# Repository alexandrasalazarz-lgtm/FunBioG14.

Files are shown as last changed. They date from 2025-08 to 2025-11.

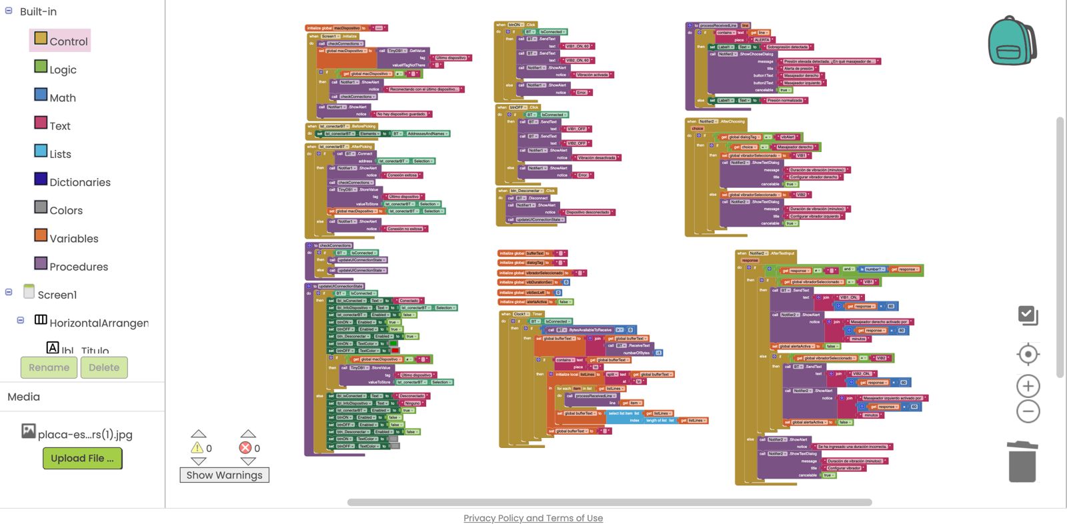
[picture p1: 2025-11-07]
ENTREGABLES/Entregable 10/Imagen aplicación .jpg

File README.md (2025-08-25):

![LOGOPUCP]((https://github.com/alexandrasalazarz-lgtm/FunBioG14./blob/cd670214b224eb7a91b062338901eb562789b06d/IMAGENES/361625433-f5917d88-32cc-4da6-9d7f-f75349cf09a3.png))

# Bienvenidos al repositorio del Grupo 14 de "Fundamentos de Biodiseño"

## Integrantes:

* **Tatiana Abigail Quispe Cueva** *tatiana.quispe@upch.edu.pe*

* **Ivanna Jael Rodriguez Cruz** *ivanna.rodriguez@upch.pe*

* **Jared Matias Neciosup Villarreal** *jared.neciosup@upch.pe*

* **Sebastian Adriano Reymundo Capcha** *sebastian.reymundo@upch.pe*

* **Luciana Mercedes Saenz Villarreal** *luciana.saenz@upch.pe*

* **Alexandra Estephania Salazar Zarate** *alexandra.salazar.z@upch.pe*

## INFORMACION DEL PROYECTO
**Temática:**

Diseñar y prototipar soluciones biomedicas para mejorar la calidad de vida de pacientes con artrosis

**Problemática:**

La artrosis es una enfermedad degenerativa la cual afecta principalmente al cartílago articular. Esta afección causa distintas limitaciones en el paciente, como dolor, rigidez y reducción del rango de movimiento en las articulaciones afectadas [1,2]. Además, según la OMS, la mayor prevalencia de esta enfermedad se encuentra en las mujeres, debido a distintos factores como factores hormonales, genéticos, mayor esperanza de vida, etc. El identificar los factores de riesgo que afectan a las mujeres podria ayudar a diseñar mejores estrategias de prevención y tratamiento en el futuro. [3]

**Justificación:**

La artrosis es una afección osteomuscular que contribuye en mayor porcentaje al total de años vividos con discapacidad. Puesto que es más prevalente en las personas de edad (alrededor del 70% son mayores de 55 años), se prevé que la prevalencia mundial de la artrosis aumente con el envejecimiento de la población. En la actualidad, a nivel mundial, 344 millones de personas que padecen esta enfermedad experimentan dolores moderados y fuertes. Esto reduce significativamente la calidad de vida que poseen, puesto que la enfermedad no solo tiene un impacto físico, sino también mental. 

**Referencias:**

[1] “Osteoarthritis,” World Health Organization, Fact Sheet, Jul. 14, 2023. [Online]. Available: https://www.who.int/news-room/fact-sheets/detail/osteoarthritis. [Accessed: Aug. 22, 2025].

[2] X. Mas Garriga, “Definición, etiopatogenia, clasificación y formas de presentación [Definition, etiology, classification and presentation forms],” Aten Primaria, vol. 46, no. Suppl 1, pp. 3–10, Jan. 2014, doi: 10.1016/S0212-6567(14)70037-X.

[3] I. A. Szilagyi *et al.*, “A systematic review of the sex differences in risk factors for knee osteoarthritis,” *Rheumatology*, vol., no., Dec. 2022, DOI: 10.1093/rheumatology/keac688.

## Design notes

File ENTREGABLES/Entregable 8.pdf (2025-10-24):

# ENTREGABLE Nº8

## Metodología VDI

Autores:

Rodríguez Cruz, Ivanna Jael

Saenz Villarreal, Luciana Mercedes

Reymundo Capcha, Sebastián Adriano

Neciosup Villarreal, Jared Matias

Salazar Zárate, Alexandra Estephania

Quispe Cueva, Tatiana Abigail

Profesor:

Juan Manuel Zuñiga

Curso:

Fundamentos de Biodiseño

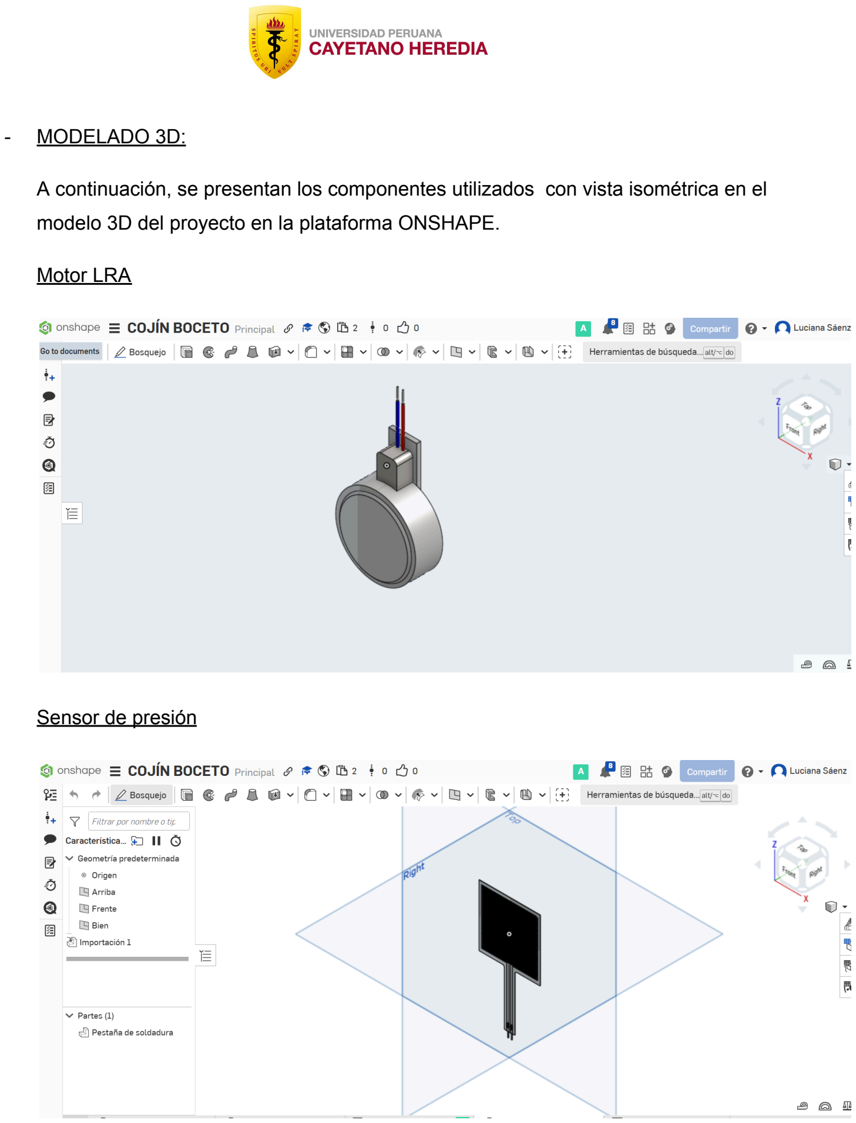
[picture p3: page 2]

- MODELADO 3D:

A continuación, se presentan los componentes utilizados con vista isométrica en el modelo 3D del proyecto en la plataforma ONSHAPE.

Motor LRA

Sensor de presión

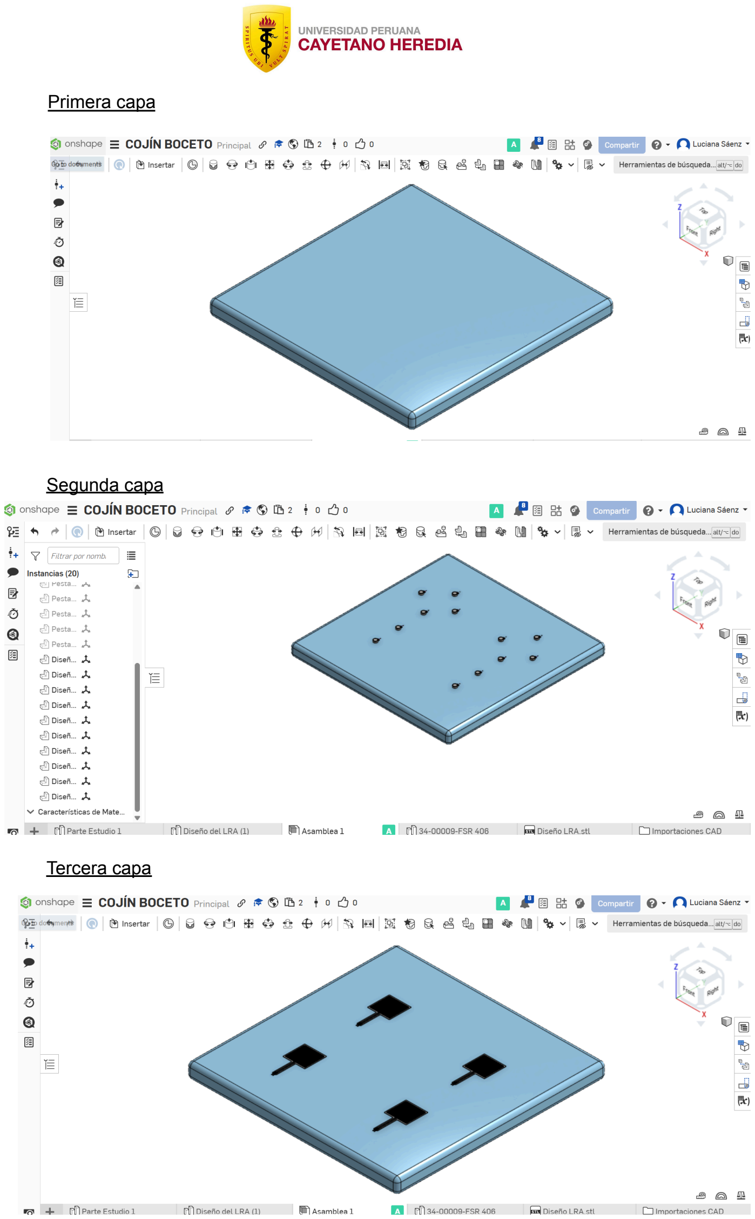
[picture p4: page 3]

Primera capa

Segunda capa

Tercera capa

Link del prototipo 3D:
https://cad.onshape.com/documents/2938b71a9a714207a594875f/w/f9e5938a32016dca3148457c/e/6e5b0f27c55fd5b3ef6440cf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 (https://cad.onshape.com/documents/2938b71a9a714207a594875f/w/f9e5938a32016dca3148457c/e/6e5b0f27c55fd5b3ef6440cf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)

Caja de componentes:

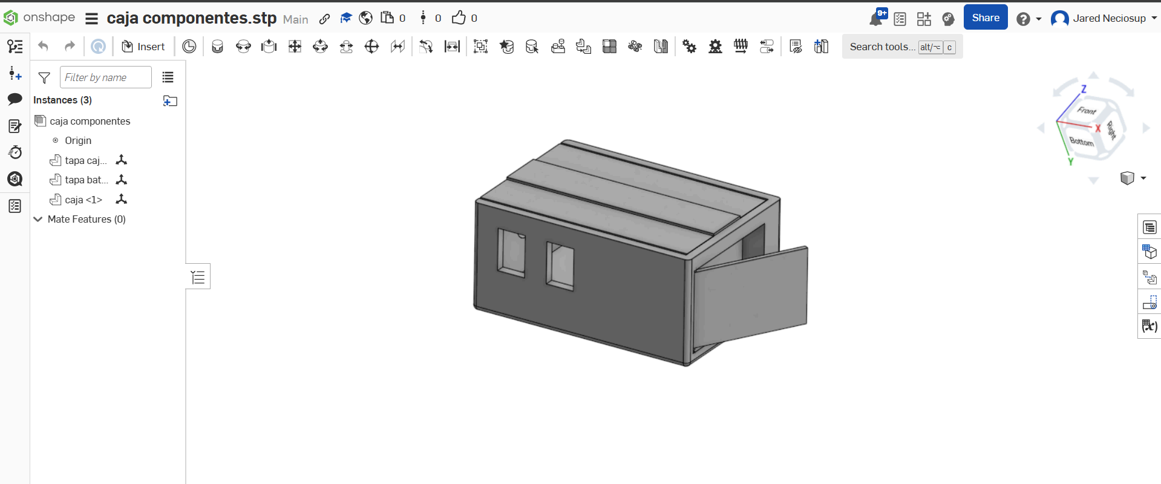
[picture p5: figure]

- Estructura:

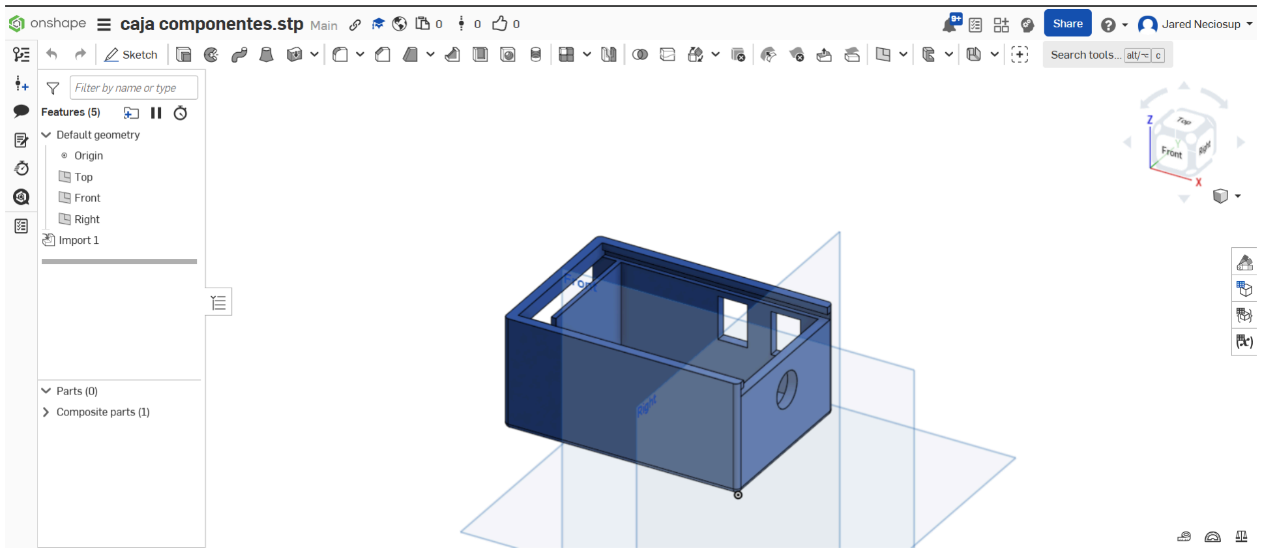
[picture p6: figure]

- Tapa:

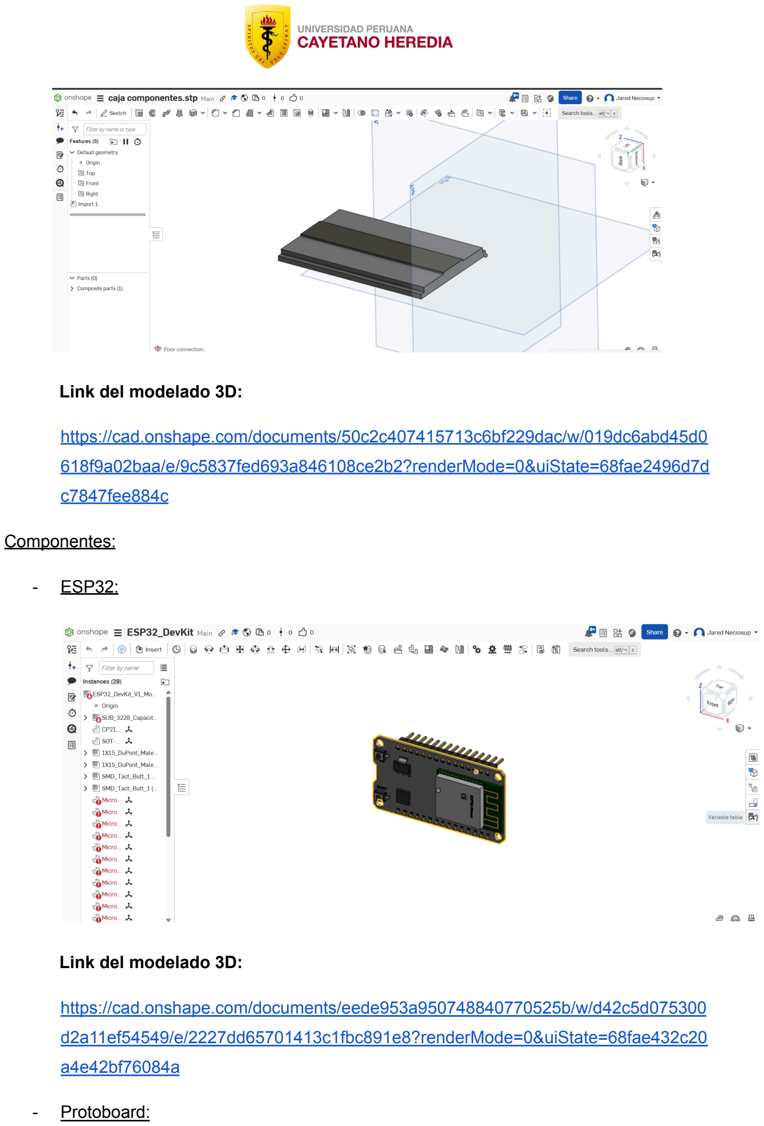
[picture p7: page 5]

Link del modelado 3D:

https://cad.onshape.com/documents/50c2c407415713c6bf229dac/w/019dc6abd45d0618f9a02baa/e/9c5837fed693a846108ce2b2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 c7847fee884c (https://cad.onshape.com/documents/50c2c407415713c6bf229dac/w/019dc6abd45d0618f9a02baa/e/9c5837fed693a846108ce2b2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)

Componentes:

- ESP32:

Link del modelado 3D:

https://cad.onshape.com/documents/eede953a950748840770525b/w/d42c5d075300d2a11ef54549/e/2227dd65701413c1fbc891e8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 a4e42bf76084a (https://cad.onshape.com/documents/eede953a950748840770525b/w/d42c5d075300d2a11ef54549/e/2227dd65701413c1fbc891e8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)

- Protoboard:

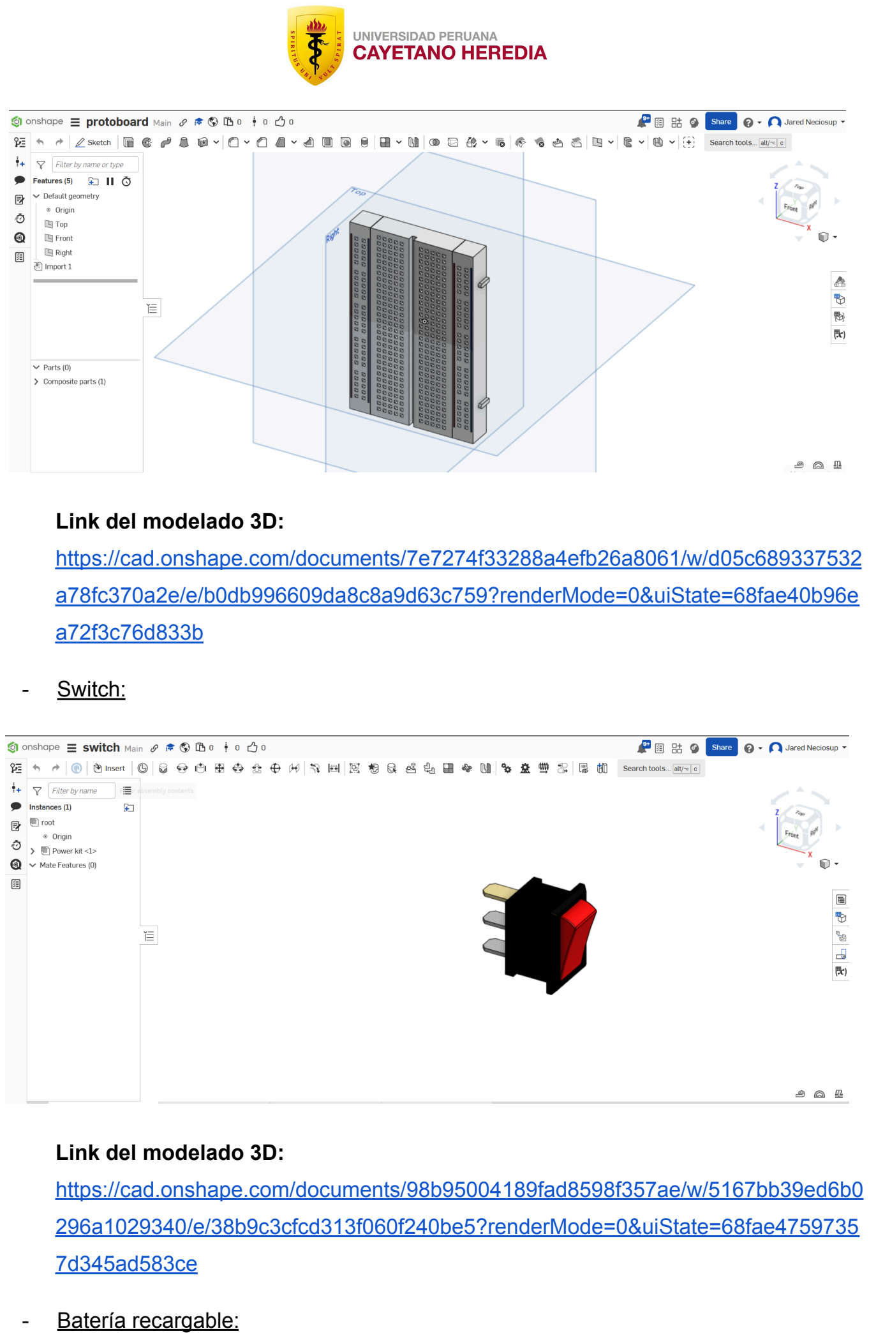
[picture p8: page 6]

Link del modelado 3D:
https://cad.onshape.com/documents/7e7274f33288a4efb26a8061/w/d05c689337532a78fc370a2e/e/b0db996609da8c8a9d63c759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 a72f3c76d833b (https://cad.onshape.com/documents/7e7274f33288a4efb26a8061/w/d05c689337532a78fc370a2e/e/b0db996609da8c8a9d63c759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)
- Switch:

Link del modelado 3D:
https://cad.onshape.com/documents/98b95004189fad8598f357ae/w/5167bb39ed6b0296a1029340/e/38b9c3cfcd313f060f240be5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 7d345ad583ce (https://cad.onshape.com/documents/98b95004189fad8598f357ae/w/5167bb39ed6b0296a1029340/e/38b9c3cfcd313f060f240be5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)
- Batería recargable:

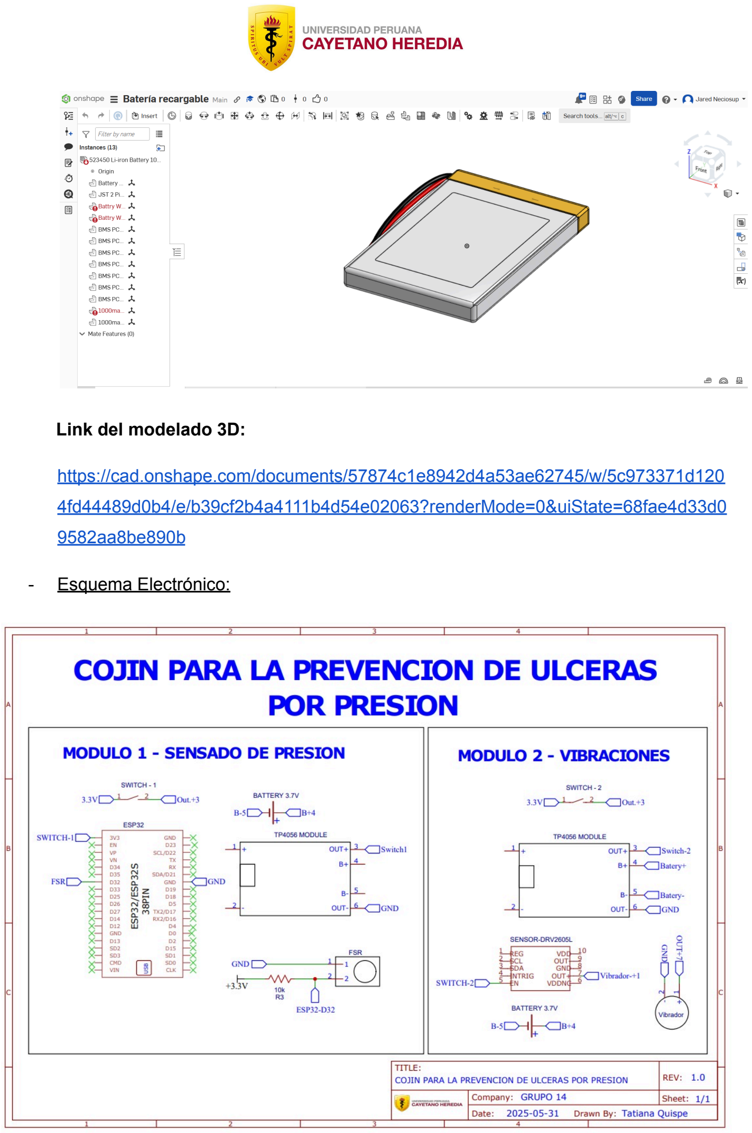
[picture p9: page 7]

Link del modelado 3D:

https://cad.onshape.com/documents/57874c1e8942d4a53ae62745/w/5c973371d1204fd44489d0b4/e/b39cf2b4a4111b4d54e02063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 9582aa8be890b (https://cad.onshape.com/documents/57874c1e8942d4a53ae62745/w/5c973371d1204fd44489d0b4/e/b39cf2b4a4111b4d54e02063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)

- Esquema Electrónico:

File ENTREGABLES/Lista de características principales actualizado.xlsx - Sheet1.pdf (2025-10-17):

Categoría principal | Campo | Características subordinadas | Explicación práctica | Requisito funcional y/o no funcional | Clasificación de requisitos
Función | Funciones principales y subordinadas | Función principal; Funciones subordinadas / secundarias | Qué hace el sistema en esencia y qué funciones complementarias lo apoyan. | El cojín debe estimular la circulación y reducir presión sostenida mediante vibración controlada (LRA). Secundariamente, debe enviar alertas y permitir la activación de la vibración desde la app. | Must have
| Flujos de energía | Entrada de energía; Conversión; Transmisión; Uso | Cómo se alimenta, transforma y usa la energía (eléctrica, mecánica, térmica, etc.). | El sistema se alimenta mediante fuente USB. La energía eléctrica sirve de fuente para alimentar el circuito, lso sensores de presion y los vibradores LRA | Must have
| Flujos de material | Transporte; Transformación; Almacenamiento; Eliminación/salida | Cómo maneja el sistema materia física (fluidos, sólidos, fuerzas transmitidas). | El sistema genera vibraciones. No transporta materiales ni almacena residuos. La elección de materiales fue además de la comodidad, la mejor trasnferencia de vibración, para que esta nos e vea afectada por las capas de materiales | Should have
| Flujos de información | Adquisición; Procesamiento; Transmisión; Almacenamiento; Visualización | Cómo capta, procesa, transmite, guarda y presenta datos. | El sistema usa sensores de presión como entradas. El ESP32 procesa los datos de presión y controla el encendido y el apagado de las vibraciones mediante una app | Must have
| Definición de interfaces | Interfaces entre subsistemas; Interacción entre disciplinas; Estándares de comunicación | Cómo se conectan las partes del sistema entre sí y con el entorno. | El sistema debe permitir la conexión segura entre Flexiforce A201 y FSR 406, ESP32y los vibradores LRA a través de cableado interno, evitando interferencias eléctricas. También debe permitir recarga segura vía conector USB. | Must have
| Geometría | Dimensiones; Requisitos de espacio; Número de unidades/módulos; Forma; Posicionamiento | Requisitos de tamaño, forma y ubicación del sistema o de sus módulos. | El cojín debe ser capaz de adaptarse a cualquier silla de ruedas prexistente por lo que sus dimensiones deben corresponder a una silla de ruedas estandar. Para la zona glútea se tendrán medidas de 0.45m de ancho 0.40m de profundidad y 0.08 m de espesor aproximadamente.El usuario solo requerirá de un producto. | Must have
| Mecánica | Integración en la máquina; Aislamiento frente a vibraciones; Movimiento; Velocidad/aceleración; Rigidez; Deformación; Tolerancias; Amortiguamiento; Resonancias; Estrés térmico; Calor por fricción | Estabilidad mecánica, precisión de movimiento y resistencia estructural. | El interior del cojín tendrá un material viscoelástico para mayor comodidad del usuario La funda (tejido 3D espaciador) debe evitar la acumulación de calor por fricción entre la funda y la piel. Malla 3D espaciadora entre capas para mantener el microclima | Should have
| Eléctrica / Electrónica | Tensión nominal; Corriente nominal; Potencia y conexiones; Compatibilidad con E-STOP; Apagado independiente de ejes; Interfaces internas/externas; Conformidad con estándares | Condiciones de alimentación, integración y seguridad eléctrica/electrónica. | Una fuentes de 10V alimentará al ESP32 y al resto del circuito. Los Flexiforce A201, FSR 406 y los vibradores estrán conectadas al microcontrolador mediante cableado interno y aislado. La espuma viscoelástica y la malla 3d espaciadora no estara en contacto directo con el usuario debido a a la funda. | Must have
| Software | Arquitectura HW/SW; Multiprocesador; Entorno de desarrollo; Lenguajes; Versionado; Actualizaciones; Modos de operación; Pruebas sin HW; Gemelo digital | Decisiones de software, modularidad y aseguramiento de calidad en simulación y pruebas. | Se divide en diferentes módulos: lectura de datos mediante los sensores de presión; procesamiento (encendido y apagado del sistema, muestra de zonas de mayor y menor presión) y actuador (vibraciones por los LRA). | Should have
| Seguridad | Seguridad funcional; Integración en parada de emergencia; Redundancia; Mecanismos fail-safe; Pruebas de seguridad | Que el sistema sea confiable y seguro en operación. | El sistema se apaga si no detecta presión o si hay fallo de sensor. Operación a bajo voltaje. | Must have
| Regulación | Cumplimiento normativo; Certificación de componentes; Disponibilidad a largo plazo; Actualizaciones remotas o locales | Asegurar conformidad normativa y sostenibilidad en el ciclo de vida. | Los componentes seleccionados (Flexiforce A201, FSR 406, ESP32, LRA) son de uso común en prototipos biomédicos y cumplen con estándares básicos de compatibilidad eléctrica. Se considerará la futura certificación del sistema si se continúa con desarrollo para uso clínico. | Should have
| Ergonomía | HMI; Claridad; Iluminación; Fuerzas de operación; Dimensiones antropométricas; Accesibilidad | Que el sistema sea fácil y seguro de usar para distintos usuarios. | No se requiere de una configuración previa para su uso, ya que se enciende y se apaga según detecte una presión. | Should have
| Diseño industrial | Codificación táctil; Háptica; Funciones estéticas; Funciones simbólicas; Reconocimiento de producto; Coloración; Orientación a segmentos | Factores de aceptación social, identidad de producto y atractivo visual. | La codificación táctil busca transmitir comodidad mediante materiales suaves y transpirables. Las funciones estéticas y simbólicas apuntan a que el producto sea agradable a la vista por lo que será de colores neutros. | Should have
| Compra | Disponibilidad de componentes; Garantía de disponibilidad; Costos de adquisición; Certificación de proveedores; Logística | Adquisición de piezas y aseguramiento de suministro. | Los Flexiforce A201, FSR 406 y el ESP32presenta alta disponibilidad local, bajo costo y garantía de continuidad de tiempo. Los LRA se encuentran con relativa facilidad en versiones genéricas. La malla 3D espaciadora y la espuma viscoelástica es común en el mercado local. En todos los casos se priorizó la compra de componentes económicos y accesibles que garanticen la viabilidad del prototipo. | Must have
| Fabricación | Procesos de fabricación; Tiempo de ciclo; Costos de producción; Nivel de automatización; Capacidad de producción; Recursos e infraestructura | Cómo se fabrica el sistema, tiempos y costos. | El proyecto contempla procesos de manufactura como cortes y costuras, además del ensamblaje de los componentes electrónicos. El tiempo de ciclo se alinea con los plazos asignados mientras que se intenta minimizar los costos de producción. | Must have

Diseño / Estructura

Realización / Producción

Control de calidad | Tolerancias; Métodos de inspección; Pruebas en proceso; Trazabilidad; Certificación de lotes | Cómo se garantiza la precisión y la fiabilidad. | ±5% en sensores Flexiforce A201, FSR 406 , ±5 mm en dimensiones del cojín.Pruebas funcionales de sensores, correcto funcionamiento de los LRA, revisión visual del ensamblaje. Validación de sensores antes del encapsulado, prueba del circuito antes del cierre y prubea de carga.Registro de lote de componentes electrónicos y fecha de ensamblaje. Certificación individual en fase piloto; muestreo estadístico en producción comercial. | Must have
Ensamblaje | Estrategia de ensamblaje; Tiempo de ensamblaje; Ergonomía del montaje; Accesibilidad; Intercambiabilidad | Cómo se montan piezas y se asegura repetibilidad. | Ensamblaje en capas: funda externa, espuma viscoelástica, malla 3d espaciadora, sensores de presión Flexiforce A201, FSR 406 con case de soporte, espuma viscoelástica, malla 3D espaciadora, vibradores LRA encapsulados, espuma viscoelástica. 1.5 horas por unidad en fase piloto; proyectado a 30 minutos con entrenamiento. Diseño modular sin herramientas especializadas; guía visual para facilitar el proceso. Componentes internos accesibles mediante apertura de funda; reemplazo de batería y sensores sin desmontaje completo. Sensores y módulos electrónicos intercambiables; conectores estandarizados. | Must have
Despliegue de software | Entorno de despliegue; Instalación local/remota; Actualizaciones automáticas/manuales; Compatibilidad; Pruebas de integración | Cómo se entrega, instala y actualiza el software. | Software cargado en microcontrolador vía USB; entorno ESP32.Instalación local en fase piloto; actualización remota vía Bluetooth en versiones avanzadas. Manuales inicialmente; sistema de actualización remota proyectado. Compatible con sensores Flexiforce A201, FSR 406 , microcontroladores ESP32.Pruebas de lectura de sensores, activación de LRA, respuesta bajo carga simulada. | Must have
Mantenimiento | Acceso a componentes; Sustitución de piezas; Limpieza; Costos de mantenimiento; Documentación | Cómo mantener el sistema funcional a lo largo del tiempo. | El diseño debe permitir un fácil acceso a los componentes internos, el cual facilite la sustitución de piezas como baterías o sensores sin necesidad de reemplazar el dispositivo completo. Para asegurar la higiene, se contempla el uso de fundas desmontables y lavables. | Must have
Uso | Uso | Facilidad de uso; Curva de aprendizaje; Experiencia de usuario; Interfaz hombre-máquina (HMI); Condiciones de operación; Seguridad del usuario; Fiabilidad/durabilidad | Cómo interactúa el usuario y en qué condiciones funciona de forma segura. | El usuario necesita de la app para manejar el sistema; eni bien esta encendido detecta la zonas de mayor presión y las muestra en la app. La experiencia es pasiva y confortable, el usuario regula la temperatura segun lo necesario | Should have
| Reciclaje | Reciclabilidad de materiales; Reutilización; Procesos de disposición final; Impacto ambiental | Qué tan sostenible es al final de su vida útil. | Los Flexiforce A201, FSR 406y componentes electrónicos son desmontables para facilitar su reutilización o reciclaje especializado. Las baterías deben desecharse en puntos autorizados para reducir impacto ambiental. | Must have
| Transporte | Portabilidad; Movilidad; Resistencia al transporte; Peso y dimensiones; Embalaje | Qué tan fácil y seguro es moverlo o transportarlo. | Debe ser portátil y ligero, no mayor a 2 kg, de modo que se coloque y retire de la silla de ruedas con facilidad. Tambiém debe ser resistente a los movimientos bruscos, compresión prolongada y golpes propios del uso. | Must have
Organización | Planificación | Costos de ciclo de vida; Disponibilidad a largo plazo; Estrategia de actualización; Capacitación y roles | Cómo se asegura la gestión a lo largo del tiempo. | El costo de ciclo de vida es bajo comparado con los gastos médicos de tratar úlceras. La disponibilidad de componentes como Flexiforce A201, FSR 406, el ESP32, y los LRA está asegurada por su uso extendido en electrónica | Must have
| Sostenibilidad | Consumo energético; Huella de carbono; Reciclabilidad; Impacto ambiental | Qué tan sostenible es el sistema durante todo su ciclo de vida. | Bajo consumo energetico debido a que ya que sensores como el Flexiforce A201, FSR 406, ESP32y los vibradores LRA con 3– 5 V. Huella ambiental reducida por los materiales son ligeros. | Must have
| Aceptación social | Atractivo cultural y simbólico; Diseño percibido; Confianza del usuario; Riesgos éticos y regulatorios | Qué tan aceptado y confiable es por la sociedad y los usuarios. | Diseño discreto, sin complejidad al usar y aceptado por usuarios. Brinda autonomia y seguridad. | Must have
| Mercado | Viabilidad comercial; Segmentación de usuarios; Diferenciación frente a competidores; Estrategia de posicionamiento | Qué tan competitivo y viable es en el mercado objetivo. | El cojín puede posicionarse de forma innovadora frente a productos convencionales al integrar la vibración, los sensores de presión y la app para visualizar las zonas de mayor riesgo apra las úlcera. Además, se debe asegurar que el dispositivo no solo cumpla con las normas técnicas de seguridad eléctrica, sino también con las disposiciones éticas sobre el manejo de datos del individuo. | Must have

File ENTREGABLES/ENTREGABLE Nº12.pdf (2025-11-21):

# ENTREGABLE Nº12

## Pruebas de uso del prototipo de baja fidelidad según plan de usabilidad

Autores:

Rodríguez Cruz, Ivanna Jael

Saenz Villarreal, Luciana Mercedes

Reymundo Capcha, Sebastián Adriano

Neciosup Villarreal, Jared Matias

Salazar Zárate, Alexandra Estephania

Quispe Cueva, Tatiana Abigail

Profesor:

Juan Manuel Zuñiga

Curso:

Fundamentos de Biodiseño

### 1. Contexto de uso:

El prototipo desarrollado corresponde a un cojín inteligente con sensores de presión y motores vibracionales, destinado a la prevención de úlceras por presión, está diseñado para ser utilizado por personas que emplean una silla de ruedas de forma continua y requieren una herramienta que ayude a redistribuir la presión en la zona isquiática para prevenir úlceras por presión. El uso principal del cojín se da cuando el usuario permanece sentado por tiempos prolongados y necesita activar periodos cortos de masaje vibracional para mejorar la circulación en la zona de apoyo.

El dispositivo puede utilizarse en distintos entornos, principalmente en el hogar, durante actividades cotidianas como estudiar, trabajar o descansar, así como en centros de rehabilitación donde los pacientes reciben supervisión terapéutica. También puede emplearse en exteriores mientras el usuario se desplaza en su silla de ruedas o permanece detenido por intervalos de más de una hora.

Las condiciones del entorno no requieren infraestructura especializada. El prototipo funciona sobre cualquier silla de ruedas estándar y solo necesita un ambiente con temperatura moderada y libre de humedad excesiva para asegurar la protección de los componentes electrónicos. La interacción del usuario con el dispositivo se realiza mediante una aplicación móvil que se conecta al cojín a través de Bluetooth, permitiendo seleccionar la duración del masaje y activar los motores vibracionales.

- Boceto final del cojín:

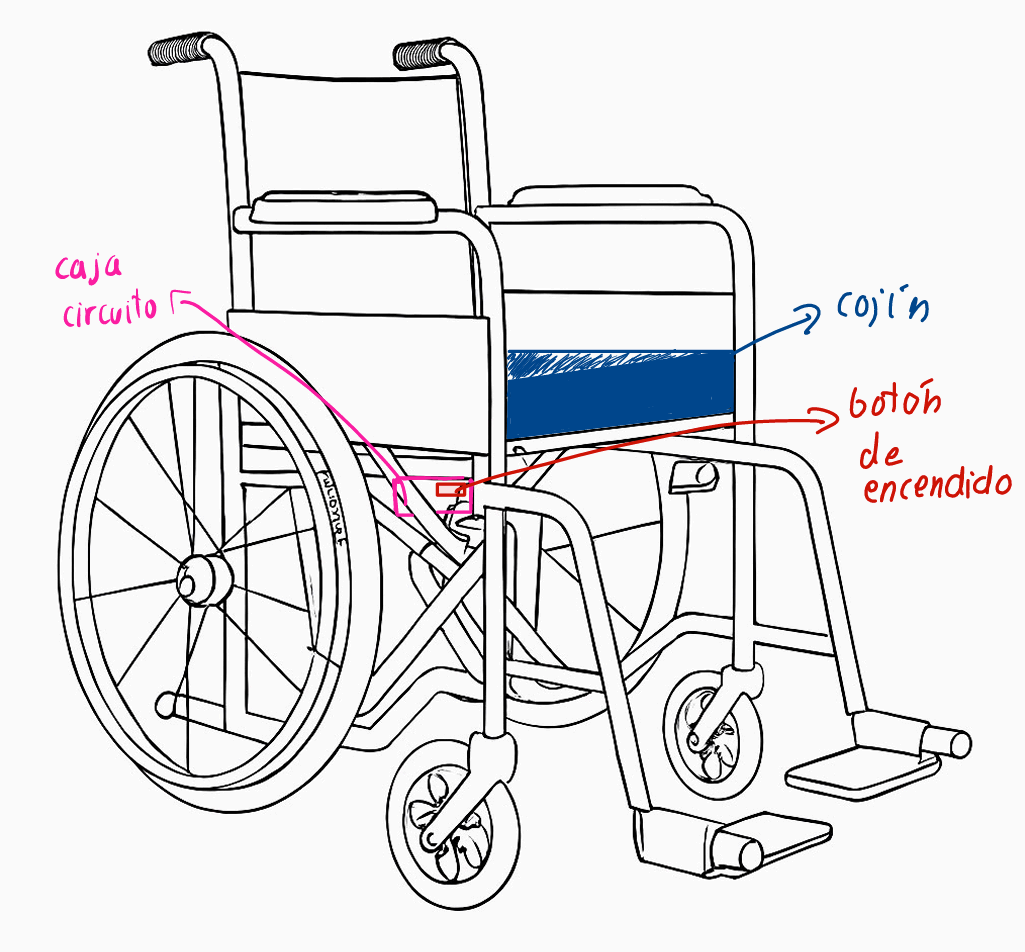
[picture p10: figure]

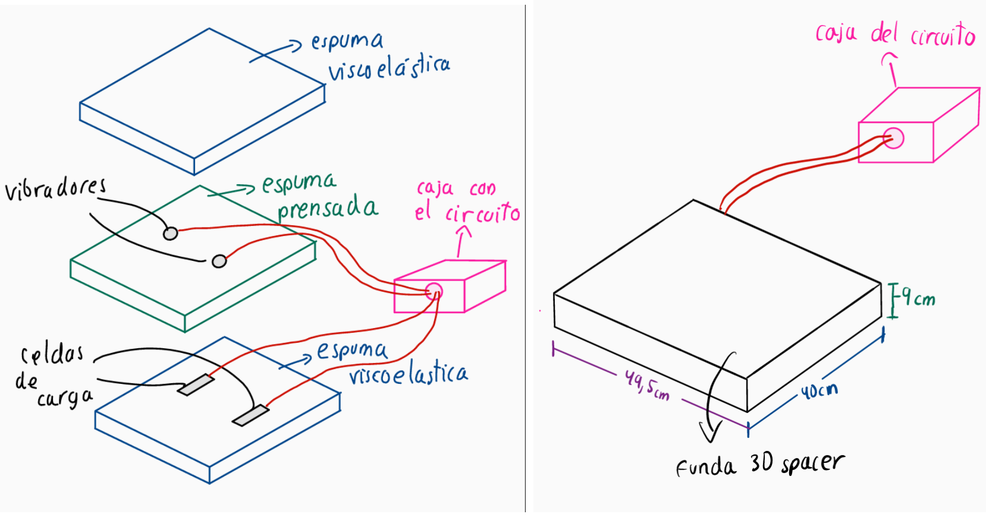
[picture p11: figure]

### 2. Perfil de usuario:

El usuario del prototipo es un paciente adulto con una lesión medular completa a nivel T4-A, lo que genera una pérdida total de la movilidad y sensibilidad en las extremidades inferiores. Debido a esta condición, presenta limitaciones motoras importantes, especialmente en la zona pélvica y las piernas, lo que lo obliga a utilizar una silla de ruedas de manera permanente. No puede detectar incomodidad ni presión excesiva en la región sacra e isquiática, lo que incrementa el riesgo de desarrollar úlceras por presión. Aun así, conserva fuerza y movilidad funcional en los miembros superiores, lo que le permite manipular su teléfono móvil, realizar tareas básicas con las manos y usar aplicaciones sin dificultad física.

En el aspecto cognitivo, el usuario no presenta déficits de comprensión ni dificultades intelectuales. Puede seguir instrucciones simples, interpretar indicadores visuales y utilizar una aplicación móvil sin inconvenientes, siempre que la interfaz sea clara, intuitiva y no requiera pasos complejos. No se evidencian limitaciones de memoria o atención que afecten el uso del dispositivo, pero sí necesita una interacción que minimice la carga cognitiva, debido a que el proceso de configuración del cojín debe ser rápido y práctico.

En cuanto a las características emocionales, el paciente puede experimentar frustración por su dependencia continua de la silla de ruedas y por las complicaciones asociadas a la falta de movilidad, especialmente si ya ha presentado lesiones por presión. Por ello, valora dispositivos que le brinden mayor autonomía, seguridad y control sobre su bienestar. Prefiere tecnologías discretas, cómodas y confiables, que no requieran asistencia constante de terceros y que le permitan sentirse más independiente en sus actividades diarias.

### 3. Análisis de tareas:

Tarea | Descripción | Riesgos potenciales | ¿Crítica? | Justificación
Colocar el cojín en la silla | Ubicar el cojín centrado en el asiento | Mala distribución de presión | Sí | Una mala posición puede generar incomodidad o presión anómala
Encender el dispositivo | Activar el switch principal | Ninguno relevante | No | No representa riesgo físico directo
Conectarse vía Bluetooth | Abrir la app y vincular con el cojín | No detectar dispositivo | No | El error no afecta la integridad del usuario
Sentarse sobre el cojín | Usar el cojín correctamente alineado | Incomodidad; presión mal distribuida | Sí | Error puede causar dolor o presión excesiva
Seleccionar tiempo de masaje | Elegir duración (1–10 minutos) | Configurar duración no deseada | No | Error leve y reversible
Activar motores LRA | Activar motor derecho, izquierdo o ambos | Exposición prolongada a vibración | Sí | Uso excesivo podría causar molestia
Finalizar sesión | Retirarse del cojín o apagar | Ninguno | No | Sin riesgo asociado

### 4. Criterios de éxito (usabilidad)

| Objetivo | Preguntas | Evidencia: Métricas
Eficacia | El usuario debe poder posicionar correctamente el cojín vibracional en la silla de ruedas y activarlo sin errores de instalación. | ¿La tarea se completó? | Se usará la métrica Task Success Rate ( o TSR) Se establece un valor objetivo de ≥ 90 % de éxito en la primera interacción para garantizar la seguridad funcional y la comprensión intuitiva en dispositivos de asistencia.
Eficiencia | El usuario debe poder colocar, conectar y encender el cojín vibracional en un tiempo breve y sin dificultad. | ¿En cuanto tiempo? | El Mean Task Completion Time evalúa la eficiencia temporal del uso. Estudios de usabilidad en dispositivos asistivos y de soporte físico establecen tiempos óptimos entre 90 y 180 s para tareas iniciales de instalación, por ello se deberá alcanzar un tiempo promedio ≤ 180 s para completar la instalación con 5 usuarios.

Satisfacció n | El usuario manifiesta que no experimenta molestias físicas asociadas a los masajes vibracionales, tales como ruido o calor y se siente seguro con el sistema | ¿Cómo lo evaluó el usuario? | Se utilizará un formato de seguimiento para inspeccionar la opinión del usuario. Además se usará la métrica a System Usability Scale. compuesta de diez ítems que evalúan la percepción subjetiva de facilidad de uso, confianza y aprendizaje del sistema, permitiendo obtener una puntuación global estandarizada de usabilidad.
Seguridad | Garantizar que el funcionamiento del cojín no genere efectos adversos en el usuario. Asegurar la fiabilidad de los sensores, evitando fallas técnicas, cortocircuitos o alertas falsas durante el uso prolongado del dispositivo. | ¿Hubo errores? | Las conexiones eléctricas del dispositivo se encuentran bien soldadas y aisladas dentro de una caja con el fin de evitar el contacto o paso de la corriente al usuario.

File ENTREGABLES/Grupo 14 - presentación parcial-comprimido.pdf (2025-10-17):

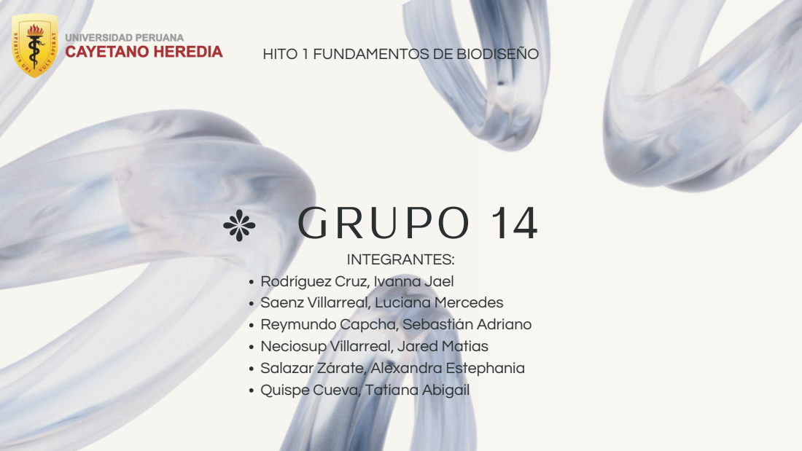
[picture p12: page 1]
GRUPO; INTEGRANTES:

HITO 1 FUNDAMENTOS DE BIODISEÑO

Rodríguez Cruz, Ivanna Jael
Saenz Villarreal, Luciana Mercedes
Reymundo Capcha, Sebastián Adriano
Neciosup Villarreal, Jared Matias
Salazar Zárate, Alexandra Estephania
Quispe Cueva, Tatiana Abigail

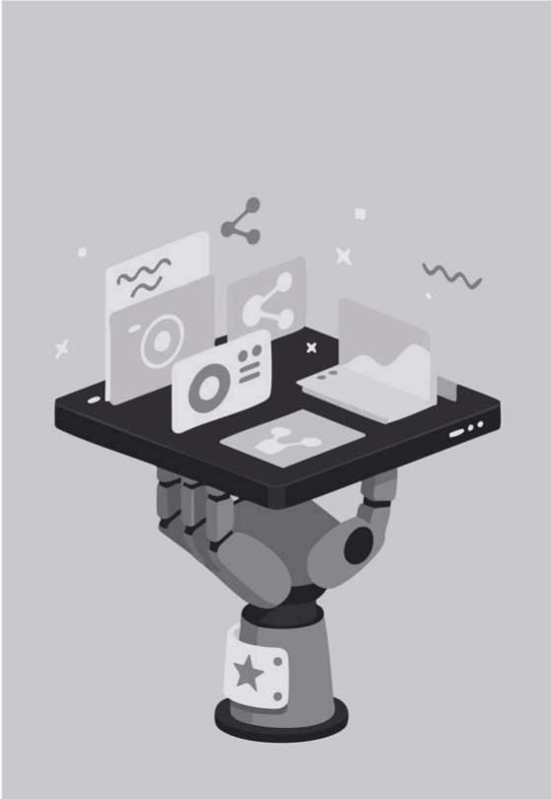
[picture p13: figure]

ATEMPORAL WWW.SITIOINCREIBLE.COM

## 1 Análisis del caso

## 4 Conclusiones / siguientes pasos

## 2 Estado del arte

## 3 Metodología VDI

# CONTENIDO

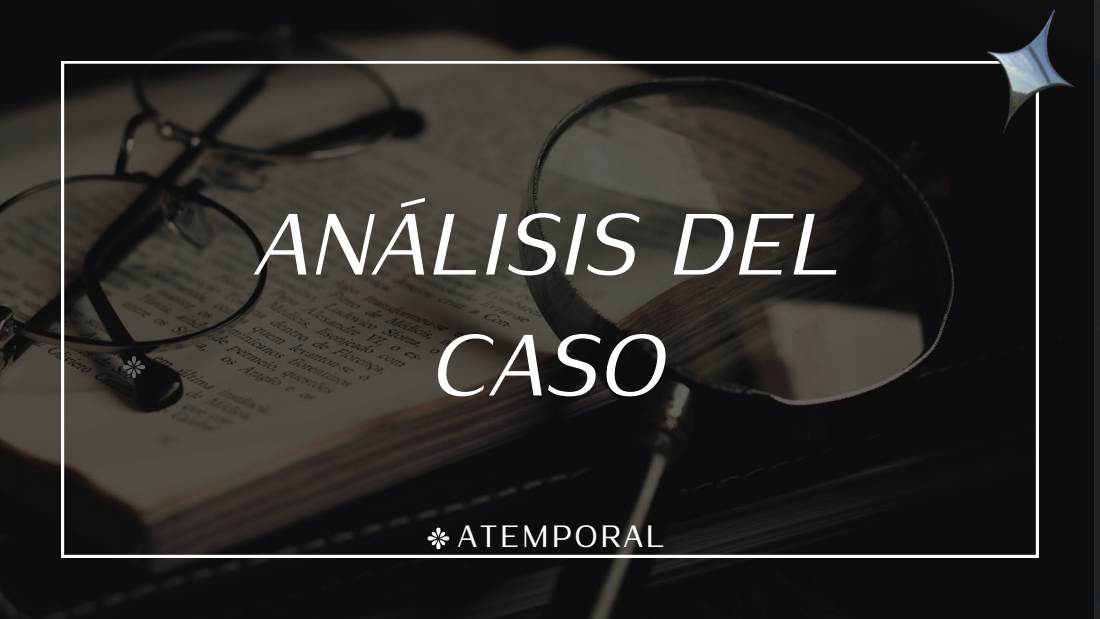
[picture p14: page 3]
ATEMPORAL; ANÁLISIS DEL CASO

## El paciente presenta una lesión medular completa a nivel T4-A, con perdida total de sensibilidad y movilidad en las piernas. La presión prolongada en zonas como el sacro y parte del glúteo general ulceras por presión

(UPP).

## A nivel mundial, 25-80% de personas con lesión medular desarrollan UPP al menos una vez

[Paquin et al., 2025].

## En Lima, la prevalencia alcanza el 21%, con predominio en la zona sacra

[Galindo et al., 2022].

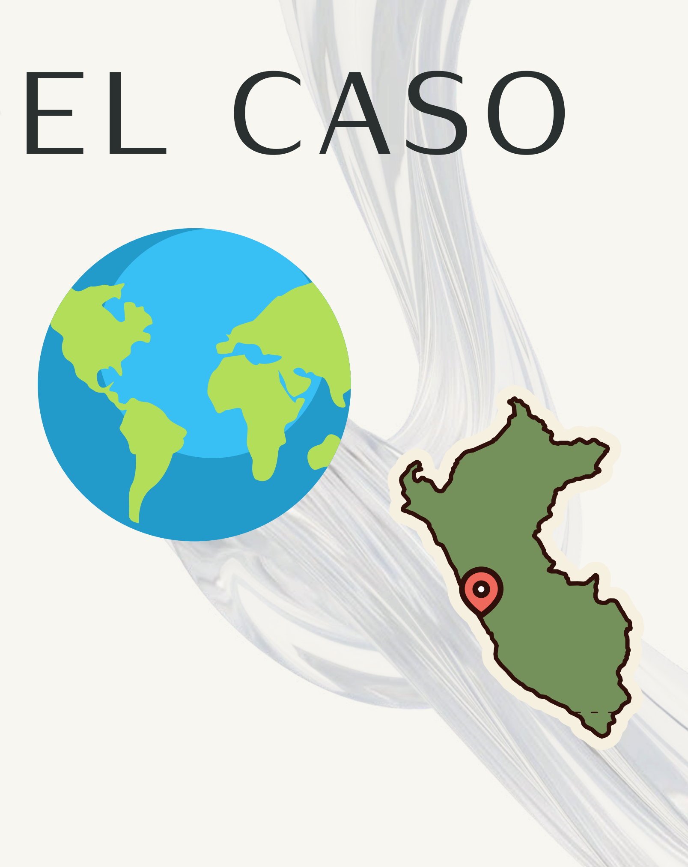
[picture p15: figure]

# ANALISIS DEL CASO

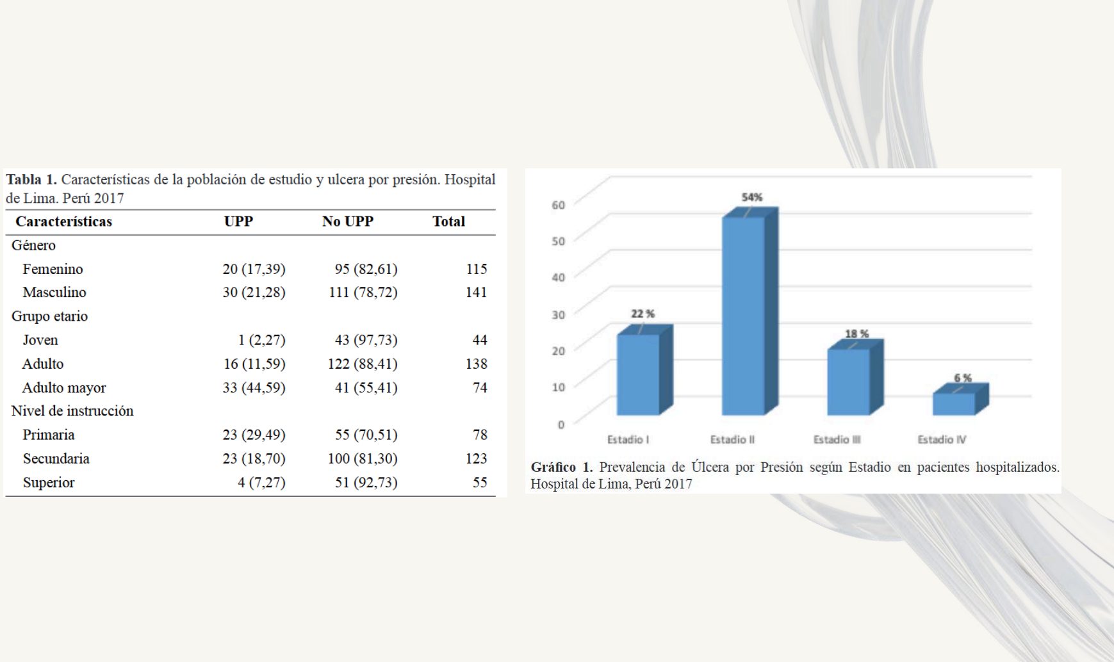
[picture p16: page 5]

# ANÁLISIS DEL CASO

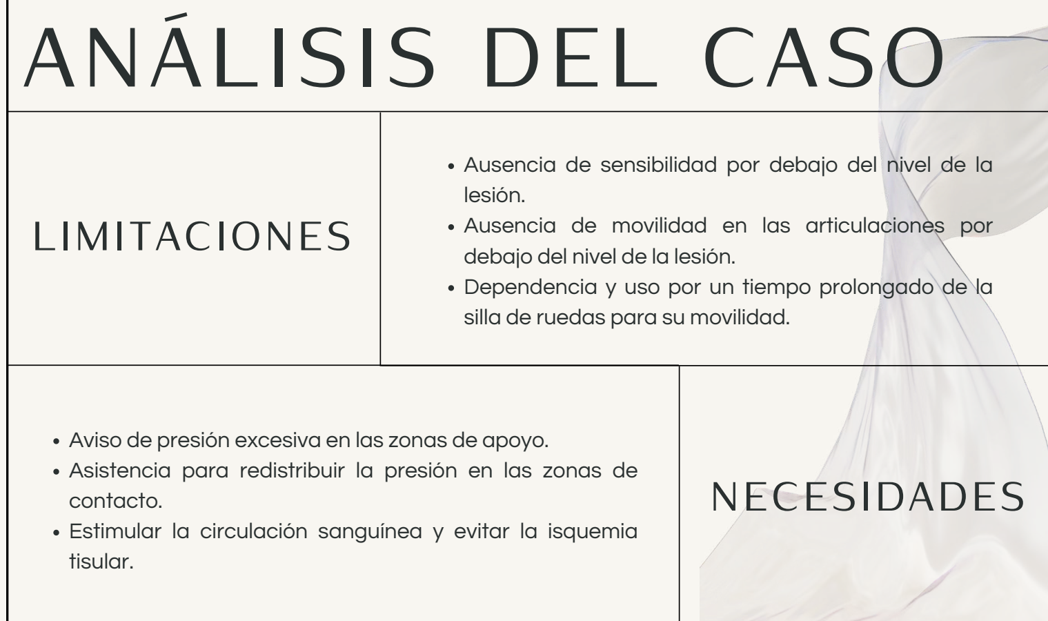
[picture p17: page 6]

### Ausencia de sensibilidad por debajo del nivel de la

lesión.

### Ausencia de movilidad en las articulaciones por

debajo del nivel de la lesión.

### Dependencia y uso por un tiempo prolongado de la

silla de ruedas para su movilidad.

Aviso de presión excesiva en las zonas de apoyo.

### Asistencia para redistribuir la presión en las zonas de

contacto.

### Estimular la circulación sanguínea y evitar la isquemia

tisular.

# LIMITACIONES

# NECESIDADES

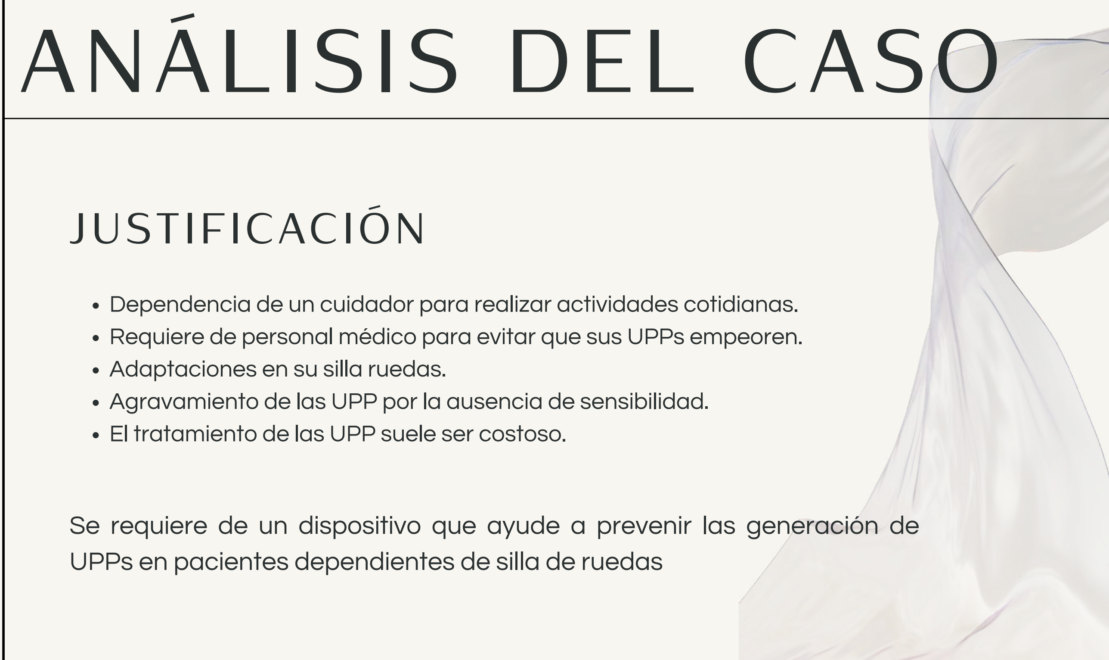
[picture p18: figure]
ANÁLISIS DEL CASO; JUSTIFICACIÓN; Adaptaciones en su silla ruedas.

Dependencia de un cuidador para realizar actividades cotidianas. Requiere de personal médico para evitar que sus UPPs empeoren.

Agravamiento de las UPP por la ausencia de sensibilidad.
El tratamiento de las UPP suele ser costoso.

## Se requiere de un dispositivo que ayude a prevenir las generación de UPPs en pacientes dependientes de silla de ruedas

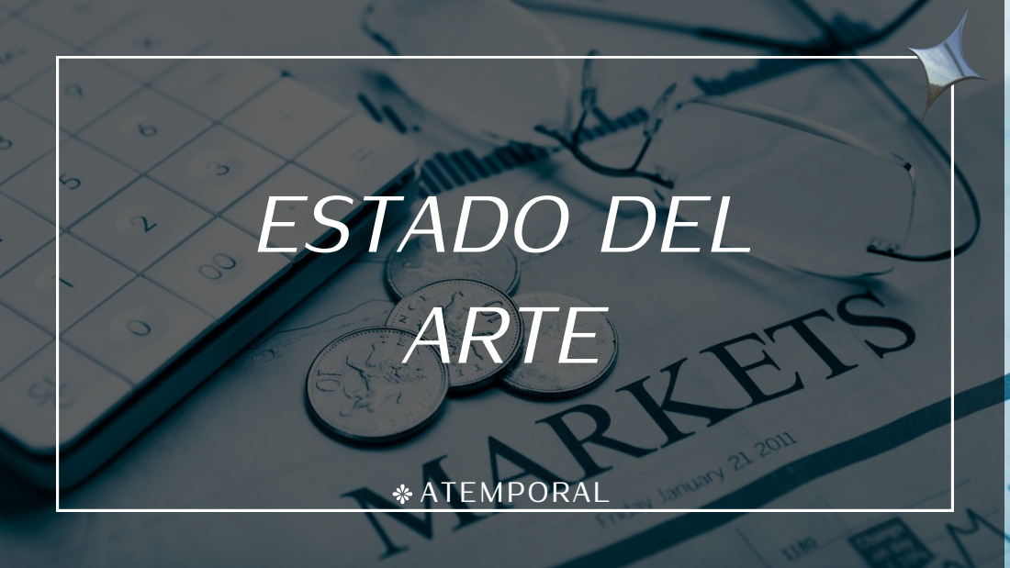
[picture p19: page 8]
ATEMPORAL; ESTADO DEL ARTE

# PATENTES

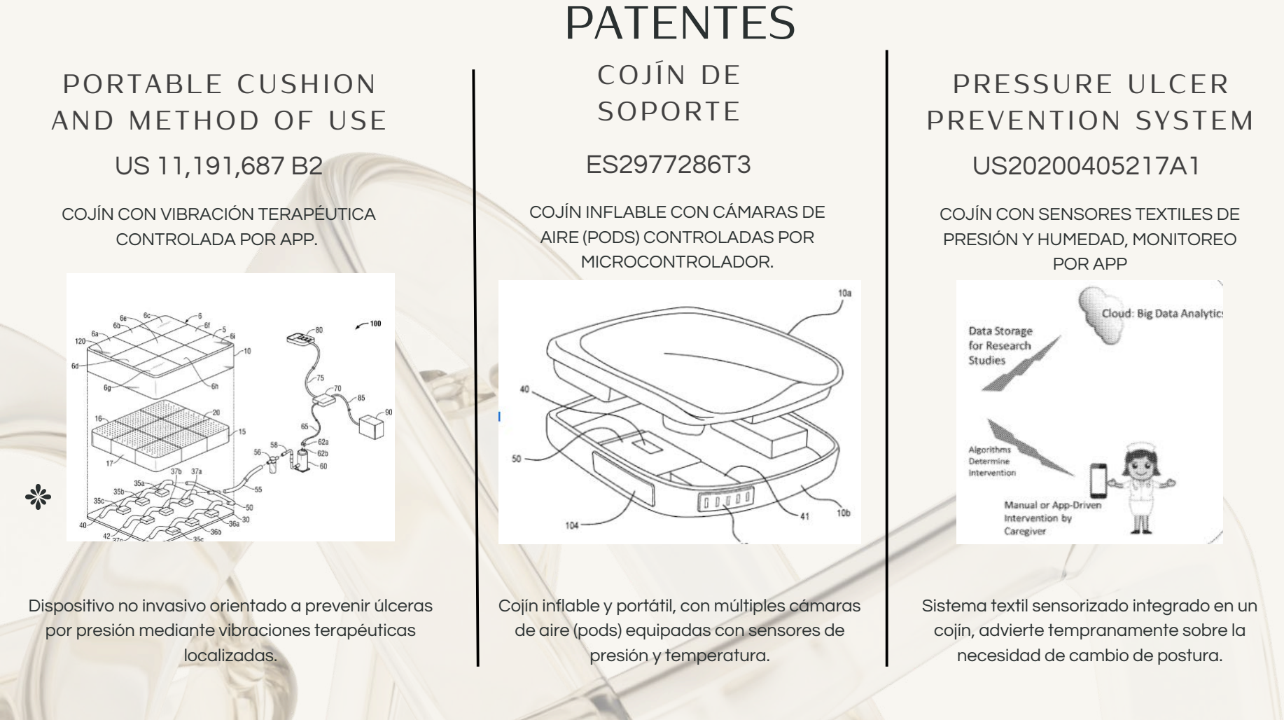
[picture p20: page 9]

COJÍN CON VIBRACIÓN TERAPÉUTICA CONTROLADA POR APP.

### ES2977286T3

### CO JÍN DE SOPORTE

### US 11,191,687 B2

### PORTABLE CUSHION AND METHOD OF USE

### US20200405217A1

### PRESSURE ULCER PREVENTION SYSTEM

COJÍN INFLABLE CON CÁMARAS DE AIRE (PODS) CONTROLADAS POR MICROCONTROLADOR.

COJÍN CON SENSORES TEXTILES DE PRESIÓN Y HUMEDAD, MONITOREO POR APP

Dispositivo no invasivo orientado a prevenir úlceras por presión mediante vibraciones terapéuticas localizadas.

Cojín inflable y portátil, con múltiples cámaras de aire (pods) equipadas con sensores de presión y temperatura.

Sistema textil sensorizado integrado en un cojín, advierte tempranamente sobre la necesidad de cambio de postura.

# PRODUCTOS COMERCIALES

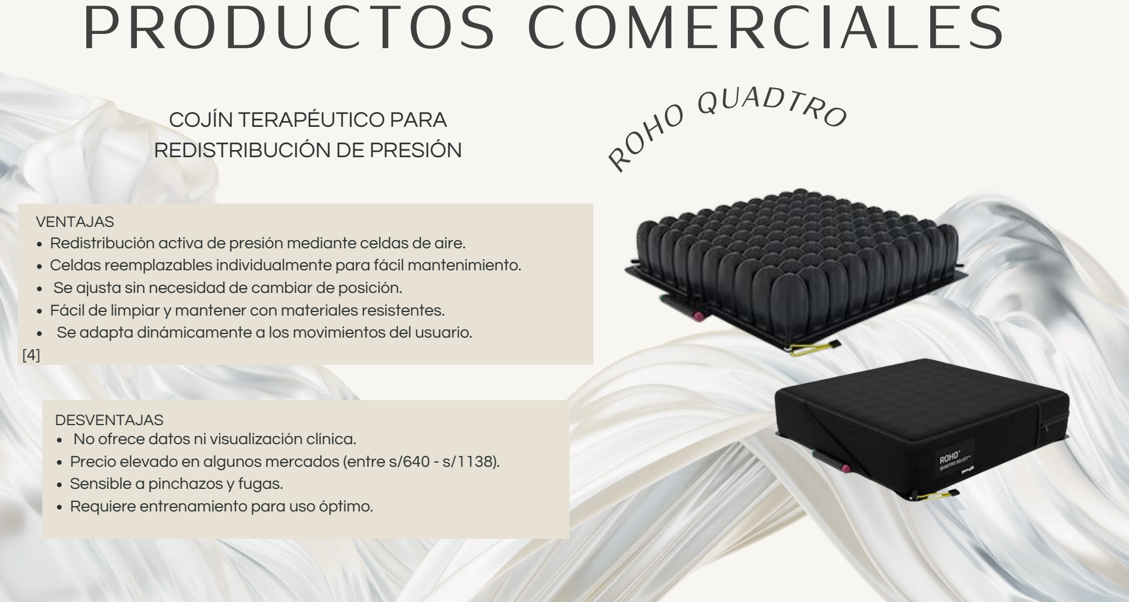
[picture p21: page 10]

# ROHO

COJÍN TERAPÉUTICO PARA

## QUADTRO

REDISTRIBUCIÓN DE PRESIÓN

VENTAJAS

DESVENTAJAS

Redistribución activa de presión mediante celdas de aire. Celdas reemplazables individualmente para fácil mantenimiento. Se ajusta sin necesidad de cambiar de posición.
Fácil de limpiar y mantener con materiales resistentes.
Se adapta dinámicamente a los movimientos del usuario.
[4]

No ofrece datos ni visualización clínica.
Precio elevado en algunos mercados (entre s/640 - s/1138). Sensible a pinchazos y fugas.
Requiere entrenamiento para uso óptimo.

# PRODUCTOS COMERCIALES

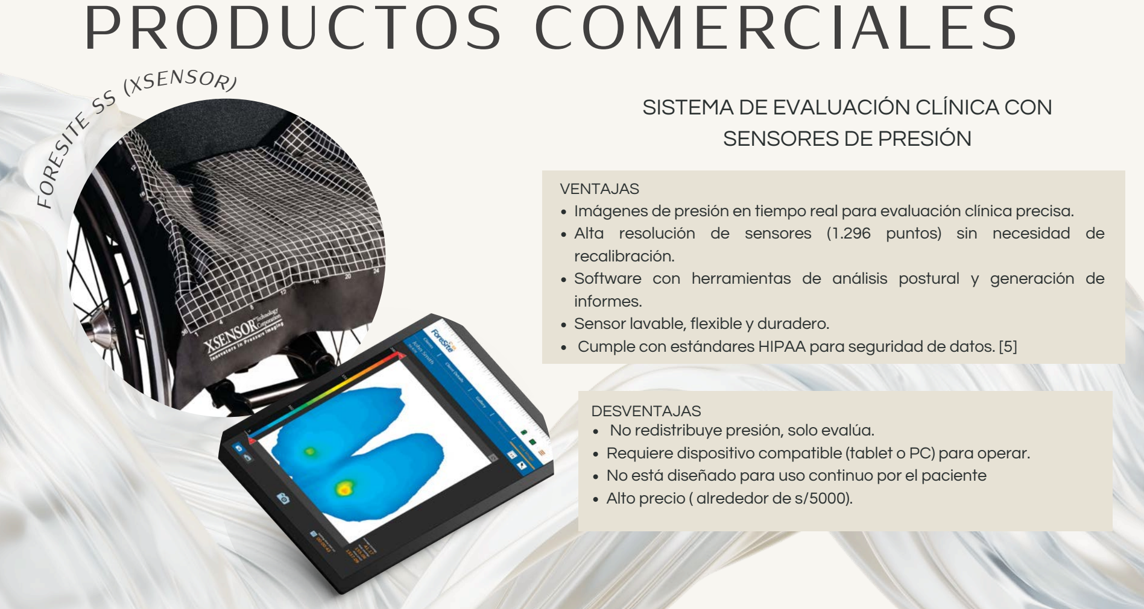
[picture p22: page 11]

FORESITE SS (XSENSOR)
SISTEMA DE EVALUACIÓN CLÍNICA CON SENSORES DE PRESIÓN

VENTAJAS

DESVENTAJAS

Imágenes de presión en tiempo real para evaluación clínica precisa. Alta resolución de sensores (1.296 puntos) sin necesidad de recalibración.
Software con herramientas de análisis postural y generación de informes.
Sensor lavable, flexible y duradero.
Cumple con estándares HIPAA para seguridad de datos. [5]

No redistribuye presión, solo evalúa.
Requiere dispositivo compatible (tablet o PC) para operar. No está diseñado para uso continuo por el paciente Alto precio ( alrededor de s/5000).

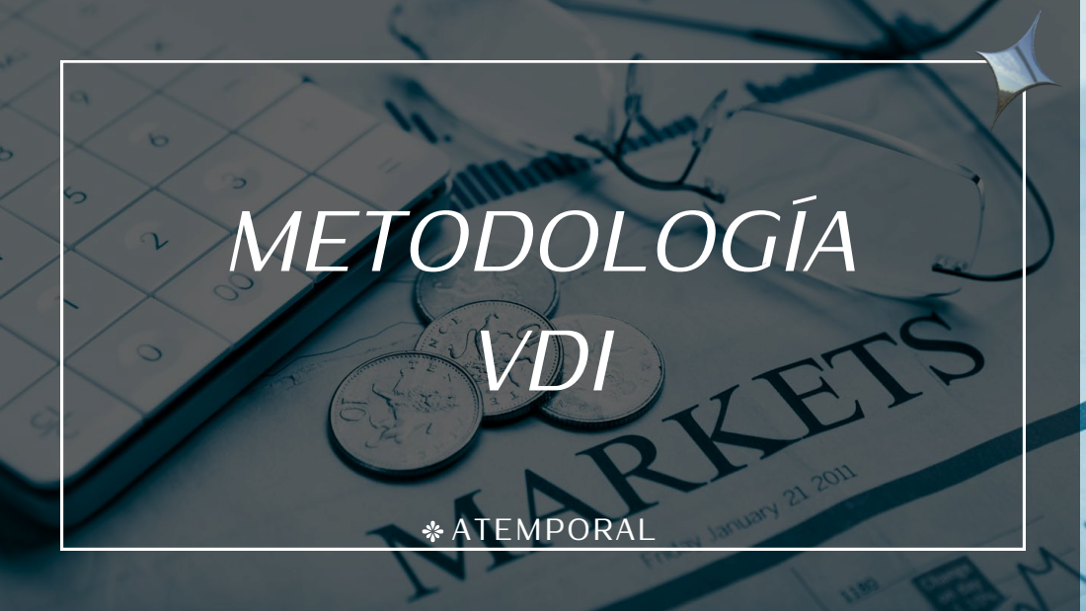
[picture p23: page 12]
ATEMPORAL; METODOLOGÍA VDI

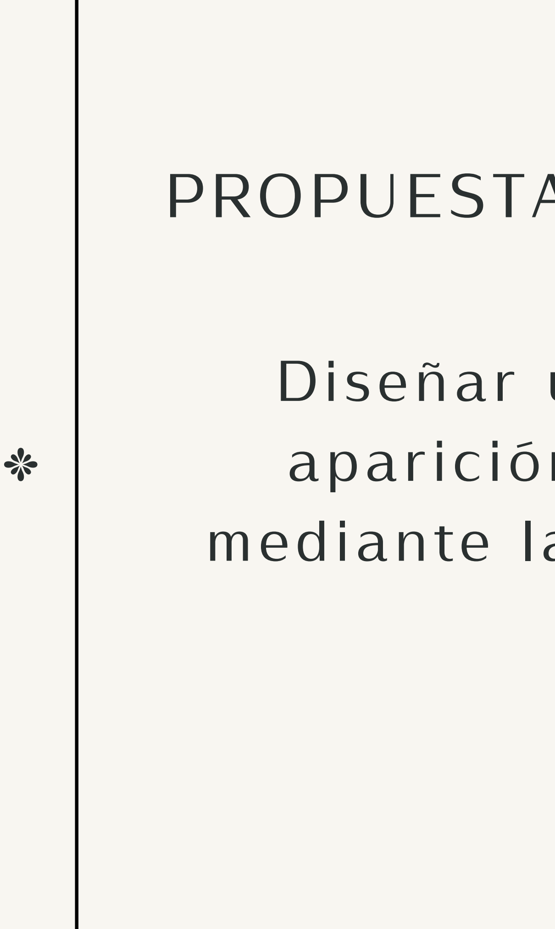
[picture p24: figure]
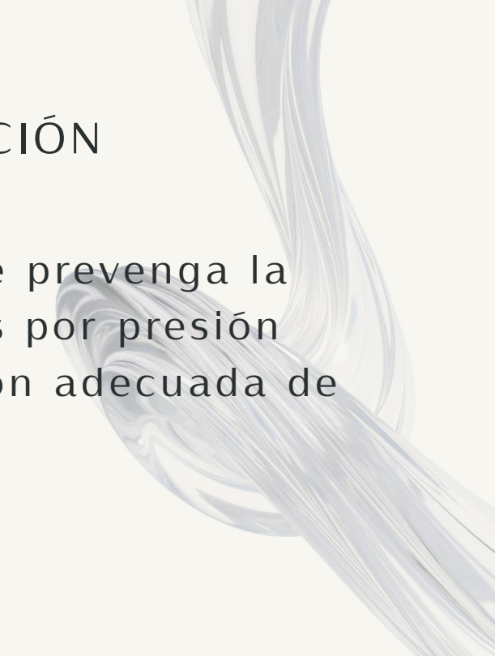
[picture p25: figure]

# PROPUESTA DE SOLUCIÓN Diseñar un cojín que prevenga la

# aparición de úlceras por presión mediante la distribución adecuada de carga

# LISTA DE REQUERIMIENTOS

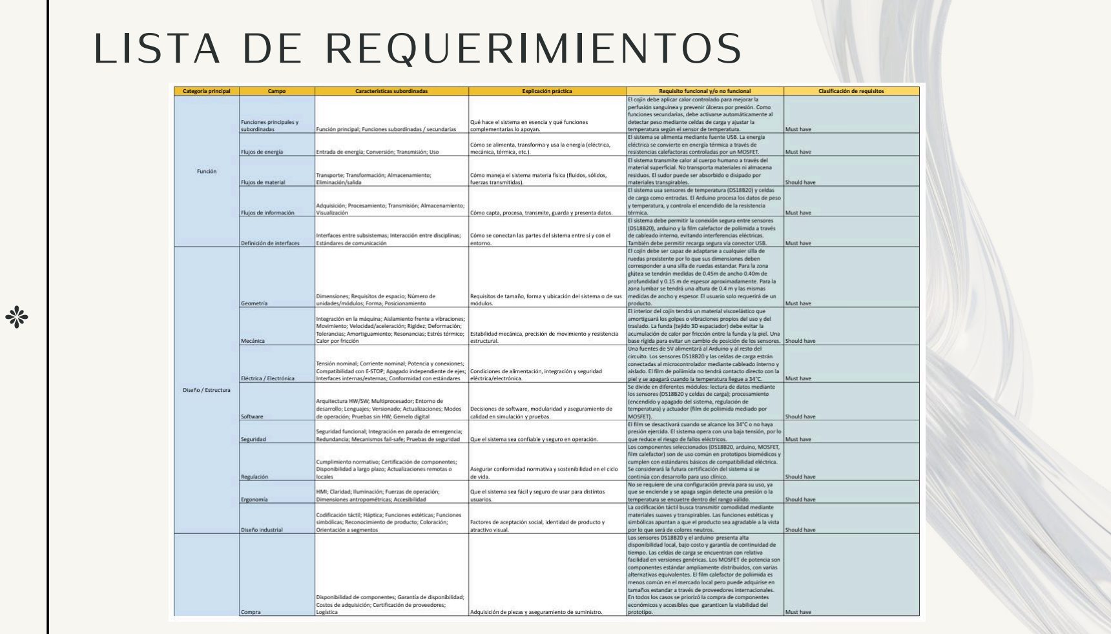
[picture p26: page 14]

# LISTA DE REQUERIMIENTOS


# ESQUEMA DE FUNCIONES



## MATRIZ MORFOLÓGICA SOLUCIÓN 2

SOLUCIÓN 1


## TABLA DE EVALUACIÓN SOLUCIÓN B

SOLUCIÓN A - PRIMERA OPCIÓN

# BOCETOS

ATEMPORAL; CONLUSIONES

# CONCLUSIONES


## El proyecto busca prevenir úlceras por presión en pacientes con lesión medular mediante un cojín inteligente que combina

sensores y vibración terapéutica.

## Esta propuesta mejora la circulación, promueve la autonomía del usuario y plantea una alternativa accesible e innovadora para la

rehabilitación y el cuidado diario.

## El diseño integra la metodología VDI, lo que asegura un enfoque estructurado desde la identificación del problema hasta la

generación de soluciones funcionales.

# REFERENCIAS


C. Paquin, F. Nindorera, M. Gagnon, M.-È. Lamontagne, y F. Routhier, «Personal risk factors for pressure injuries among wheelchair users: an umbrella review of new insights in 2024», Disability And Rehabilitation Assistive Technology, pp. 1-16, ene. 2025, doi: 10.1080/17483107.2024.2448161.
M. V. G. Galindo, B. H. Flores, y Y. Musayón-Oblitas, «Prevalencia de Úlcera por Presión en Pacientes Hospitalizados de un Hospital de Lima», Revista Enfermería Herediana, vol. 13, pp. 20-27, mar. 2022, doi: 10.20453/renh.v13i0.4146. Li C, Chen Y, Yao G, Lv Q, Xu T, Zhang S, et al. The global prevalence of pressure injuries among people with spinal cord injury: a systematic review and meta-analysis. BMC Musculoskelet Disord. 2020;21(1):603. doi:10.1186/s12891-020-03369-
Crealey S, Regan J, Richardson K. Cojín de soporte. Patente ES2977286T3. 2022.
Sachdev HS, Sachdev KS. Portable cushion and method of use. Patente US 11,191,687 B2. 2021.
Jayaraman S, Park S. Pressure ulcer prevention system. Patente US20200405217A1. 2020.

# GRACIAS

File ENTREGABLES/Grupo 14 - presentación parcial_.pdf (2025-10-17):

GRUPO; INTEGRANTES:

HITO 1 FUNDAMENTOS DE BIODISEÑO

Rodríguez Cruz, Ivanna Jael
Saenz Villarreal, Luciana Mercedes
Reymundo Capcha, Sebastián Adriano
Neciosup Villarreal, Jared Matias
Salazar Zárate, Alexandra Estephania
Quispe Cueva, Tatiana Abigail

WWW.SITIOINCREIBLE.COM; 1 Análisis del caso; 4 Conclusiones / siguientes pasos; 2 Estado del arte; 3 Metodología VDI; CONTENIDO
ATEMPORAL; ANÁLISIS DEL CASO

## El paciente presenta una lesión medular completa a nivel T4-A, con perdida total de sensibilidad y movilidad en las piernas. La presión prolongada en zonas como el sacro y parte del glúteo general ulceras por presión

(UPP).

## A nivel mundial, 25-80% de personas con lesión medular desarrollan UPP al menos una vez

[Paquin et al., 2025].

## En Lima, la prevalencia alcanza el 21%, con predominio en la zona sacra

[Galindo et al., 2022].


# ANALISIS DEL CASO


# ANÁLISIS DEL CASO


### Ausencia de sensibilidad por debajo del nivel de la

lesión.

### Ausencia de movilidad en las articulaciones por

debajo del nivel de la lesión.

### Dependencia y uso por un tiempo prolongado de la

silla de ruedas para su movilidad.

Aviso de presión excesiva en las zonas de apoyo.

### Asistencia para redistribuir la presión en las zonas de

contacto.

### Estimular la circulación sanguínea y evitar la isquemia

tisular.

# LIMITACIONES

# NECESIDADES

ANÁLISIS DEL CASO; JUSTIFICACIÓN; Adaptaciones en su silla ruedas.

Dependencia de un cuidador para realizar actividades cotidianas. Requiere de personal médico para evitar que sus UPPs empeoren.

Agravamiento de las UPP por la ausencia de sensibilidad.
El tratamiento de las UPP suele ser costoso.

## Se requiere de un dispositivo que ayude a prevenir las generación de UPPs en pacientes dependientes de silla de ruedas

ATEMPORAL; ESTADO DEL ARTE

# PATENTES


COJÍN CON VIBRACIÓN TERAPÉUTICA CONTROLADA POR APP.

### ES2977286T3

### COJ ÍN DE SOPORTE

### US 11,191,687 B2

### PORTABLE CUSHION AND METHOD OF USE

### US20200405217A1

### PRESSURE ULCER PREVENTION SYSTEM

COJÍN INFLABLE CON CÁMARAS DE AIRE (PODS) CONTROLADAS POR MICROCONTROLADOR.

COJÍN CON SENSORES TEXTILES DE PRESIÓN Y HUMEDAD, MONITOREO POR APP

Dispositivo no invasivo orientado a prevenir úlceras por presión mediante vibraciones terapéuticas localizadas.

Cojín inflable y portátil, con múltiples cámaras de aire (pods) equipadas con sensores de presión y temperatura.

Sistema textil sensorizado integrado en un cojín, advierte tempranamente sobre la necesidad de cambio de postura.

# PRODUCTOS COMERCIALES


# ROHO

COJÍN TERAPÉUTICO PARA

## QUADTRO

REDISTRIBUCIÓN DE PRESIÓN

VENTAJAS

DESVENTAJAS

Redistribución activa de presión mediante celdas de aire. Celdas reemplazables individualmente para fácil mantenimiento. Se ajusta sin necesidad de cambiar de posición.
Fácil de limpiar y mantener con materiales resistentes.
Se adapta dinámicamente a los movimientos del usuario.
[4]

No ofrece datos ni visualización clínica.
Precio elevado en algunos mercados (entre s/640 - s/1138). Sensible a pinchazos y fugas.
Requiere entrenamiento para uso óptimo.

# PRODUCTOS COMERCIALES


FORESITE SS (XSENSOR)
SISTEMA DE EVALUACIÓN CLÍNICA CON SENSORES DE PRESIÓN

VENTAJAS

DESVENTAJAS

Imágenes de presión en tiempo real para evaluación clínica precisa. Alta resolución de sensores (1.296 puntos) sin necesidad de recalibración.
Software con herramientas de análisis postural y generación de informes.
Sensor lavable, flexible y duradero.
Cumple con estándares HIPAA para seguridad de datos. [5]

No redistribuye presión, solo evalúa.
Requiere dispositivo compatible (tablet o PC) para operar. No está diseñado para uso continuo por el paciente Alto precio ( alrededor de s/5000).

ATEMPORAL; METODOLOGÍA VDI


# PROPUESTA DE SOLUCIÓN

# Diseñar un cojín que prevenga la aparición de úlceras por presión mediante la distribución adecuada de carga

# LISTA DE REQUERIMIENTOS


# LISTA DE REQUERIMIENTOS


# ESQUEMA DE FUNCIONES



## MATRIZ MORFOLÓGICA

SOLUCIÓN 2

SOLUCIÓN 1


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
# BOCETOS

ATEMPORAL; CONLUSIONES

# CONCLUSIONES


## El proyecto busca prevenir úlceras por presión en pacientes con lesión medular mediante un cojín inteligente que combina

sensores y vibración terapéutica.

## Esta propuesta mejora la circulación, promueve la autonomía del usuario y plantea una alternativa accesible e innovadora para la

rehabilitación y el cuidado diario.

## El diseño integra la metodología VDI, lo que asegura un enfoque estructurado desde la identificación del problema hasta la

generación de soluciones funcionales.

# REFERENCIAS


C. Paquin, F. Nindorera, M. Gagnon, M.-È. Lamontagne, y F. Routhier, «Personal risk factors for pressure injuries among wheelchair users: an umbrella review of new insights in 2024», Disability And Rehabilitation Assistive Technology, pp. 1-16, ene. 2025, doi: 10.1080/17483107.2024.2448161.
M. V. G. Galindo, B. H. Flores, y Y. Musayón-Oblitas, «Prevalencia de Úlcera por Presión en Pacientes Hospitalizados de un Hospital de Lima», Revista Enfermería Herediana, vol. 13, pp. 20-27, mar. 2022, doi: 10.20453/renh.v13i0.4146. Li C, Chen Y, Yao G, Lv Q, Xu T, Zhang S, et al. The global prevalence of pressure injuries among people with spinal cord injury: a systematic review and meta-analysis. BMC Musculoskelet Disord. 2020;21(1):603. doi:10.1186/s12891-020-03369-
Crealey S, Regan J, Richardson K. Cojín de soporte. Patente ES2977286T3. 2022.
Sachdev HS, Sachdev KS. Portable cushion and method of use. Patente US 11,191,687 B2. 2021.
Jayaraman S, Park S. Pressure ulcer prevention system. Patente US20200405217A1. 2020.

# GRACIAS

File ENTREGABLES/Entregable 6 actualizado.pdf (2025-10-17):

# ENTREGABLE Nº6

### Entendiendo al usuario

Autores:

Rodríguez Cruz, Ivanna Jael

Saenz Villarreal, Luciana Mercedes

Reymundo Capcha, Sebastián Adriano

Neciosup Villarreal, Jared Matias

Salazar Zárate, Alexandra Estephania

Quispe Cueva, Tatiana Abigail

Profesor:

Juan Manuel Zuñiga

Curso:

Fundamentos de Biodiseño

Checkpoint 1 – Business Case - ¿Por qué hacemos este proyecto?

- Situación inicial

¿Cuál es el problema, necesidad o contexto que motiva el desarrollo?

El problema presente en el caso es la prevalencia de úlceras por presión (UPP) en individuos con lesión medular completa, quienes al estar inmovilizados en sus extremidades requieren del uso de silla de ruedas. Aquello provoca presión y aumento de temperatura constante en zonas específicas, como el sacro, generando complicaciones clínicas que afectan la salud, retrasan la rehabilitación y disminuyen la calidad de vida. En ese sentido, se enfatiza la necesidad de un dispositivo adaptado a una silla de ruedas que contribuya a la prevención de las UPP.

- Objetivos estratégicos

¿Qué metas técnicas, económicas y organizativas debe cumplir el proyecto?

Metas técnicas

- El cojín debe detectar presión en zonas anatómicas críticas mediante sensores tipo HX711 o ESR406.
- Contribuir a la prevención de UPP mediante microvibraciones localizadas con motores LRA y controlar el sistema mediante un microcontrolador ESP32 con conectividad Bluetooth.
- Integrar una app móvil para configurar sesiones de masaje y recibir alertas.
- Debe ser cómodo, silencioso, ligero y capaz de adaptarse a cualquier silla de ruedas preexistente.

Metas económicas
- Buscar un costo de producción competitivo frente a cojines con el mismo objetivo
- Bajo consumo eléctrico para permitir uso prolongado con mínima factura eléctrica
- Selección de componentes electrónicos de disponibilidad comercial y materiales de cubierta lavables y duraderos.
- El dispositivo debe justificar su costo al reducir complicaciones médicas y de tratamientos derivados de úlceras avanzadas.

Metas organizativas
- Lograr al menos una prueba básica que demuestre el funcionamiento parcial o conceptual de la idea.
- Realizar una gestión adecuada de los recursos disponibles y evitar gastos innecesarios para la elaboración del cojín.

- Valor añadido

¿Qué beneficio aporta el sistema (para el usuario, para la empresa, para la sociedad)?

El cojín que se quiere diseñar aporta beneficios al paciente al prevenir úlceras por presión (UPP) de forma activa. A diferencia de otros dispositivos de alivio pasivo, este sistema combina el monitoreo en tiempo real de la presión mediante celdas de carga y la intervención terapéutica activa a través de vibraciones , todo controlado por una aplicación móvil. Esta combinación garantiza un mecanismo de prevención eficiente: el sistema de celdas de carga detecta las zonas de mayor concentración de presión, y la aplicación (accesible al paciente o cuidador) puede activar de forma manual o automática el sistema de vibraciones.

Asimismo, el usuario también tendrá un beneficio en su calidad de vida, ya que el cojín no solo previene complicaciones clínicas, sino que también favorece el confort mientras que el paciente esté sentado durante períodos prolongados. Se ha comprobado que la vibroterapia es una intervención activa superior al tratamiento estándar en la curación de UPP de etapa I y se traduce en una mayor tasa de curación [a]. La capacidad de gestionar y visualizar los puntos de presión de alto riesgo a través de la aplicación reduce la ansiedad y el riesgo de úlceras.

Finalmente, el diseño con detección automática mediante sensores de presión y control vía app aumenta la tranquilidad del paciente, ya que asegura que el dispositivo solo funcione cuando se detecta presión de riesgo, optimizando la intervención, la energía y reduciendo riesgos. Este enfoque se inspira en tecnologías aplicadas en camas inteligentes que utilizan sensores de carga para vigilar el peso y la posición del paciente, activando funciones automáticas para reducir complicaciones [b]. En conjunto, estos elementos hacen del cojín una herramienta innovadora que protege al paciente de las UPP mediante una estrategia de intervención activa , aporta comodidad diaria y refuerza su seguridad, consolidándose como una ayuda fundamental en la vida cotidiana de personas en situación de vulnerabilidad y pérdida de movimiento.

- Stakeholders

Usuarios directos:

- Pacientes en silla de ruedas (con movilidad reducida o sin movilidad).
- Cuidadores (familiares o terceros encargados).

Clientes:

- Hospitales y clínicas.
- Centros de rehabilitación.
- Sistema de salud pública.
- Aseguradoras de salud (para reducir costos por complicaciones). Partes interesadas clave

- Profesionales de salud (enfermeros/as, fisioterapeutas, médicos especialistas)
- Fabricantes de dispositivos médicos
- Universidades y centros de investigación
- Asociaciones y ONG 's.
- Competencias y equipo

Nos encontramos cursando el último ciclo de generales en nuestra carrera, por ende nuestras habilidades y acceso a recursos e información especializada es limitado. Sin embargo, contamos con el conocimiento suficiente para el desarrollo y avance de este proyecto. Gracias a lo aprendido hasta el momento y lo que aprenderemos durante el curso, tenemos buenas bases en biodiseño, modelado en CAD, electrónica básica, programación, etc, lo cual nos permite entender el funcionamiento del cojín y cómo se adaptará al caso de nuestro paciente. También disponemos de laboratorios en nuestras universidades y la asesoría de nuestros profesores para orientarnos y ayudarnos en lo que necesitamos. En esta etapa, si bien no podemos realizar un prototipo avanzado, podemos realizar una propuesta de manera funcional y viable.

- Planificación inicial

Cronograma preliminar:

- Semana 1–2-3-4: investigación de usuario y benchmarking de tecnologías.
- Semana 5-6-7-8: diseño conceptual, selección de sensores y hardware.
- Semana 9-10-11-12: prototipo inicial y pruebas en laboratorio.
- Semana 13-14-15-16: pruebas piloto con paciente, iteración de mejoras.

Presupuesto:

Este monto corresponde al costo estimado de los componentes principales del prototipo del cojín sensorizado para prevención de úlceras por presión resulta de S/. 224 - 250.

Posible Riesgos:

1. Fallas en sensores: error en medición de presión o en las vibraciones por mala calibración o desgaste.
2. Durabilidad del material: la espuma viscoelástica puede perder propiedades con el uso prolongado.
3. Aceptación del usuario: incomodidad inicial por el grosor del cojín o dudas sobre la confiabilidad del sistema.
4. Mantenimiento: necesidad de limpiar la funda y revisar el estado de los sensores periódicamente.
5. Errores en software: alarmas falsas o falta de alertas oportunas que reduzcan la efectividad.

Referencias bibliográficas:

[a] Saragih, A., et al. (2024). Vibration therapy for patients with hard-to-heal wounds. [Journal Name].

[b] Silva A, Metrôlho J, Ribeiro F, et al. A Review of Intelligent Sensor-Based Systems for Pressure Ulcer Prevention. Computers. 2022;11(1):6.

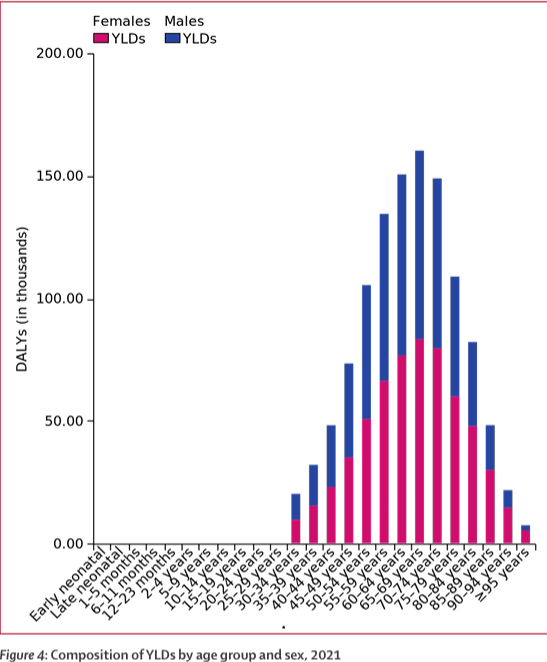
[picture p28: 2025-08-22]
IMAGENES/image.png

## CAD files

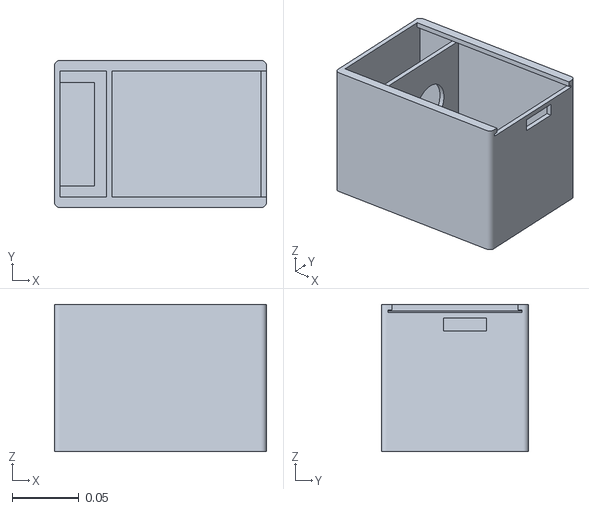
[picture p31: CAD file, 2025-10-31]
ENTREGABLES/ENTREGABLE 9/Part Studio 1.stl
0.159 x 0.11 x 0.11

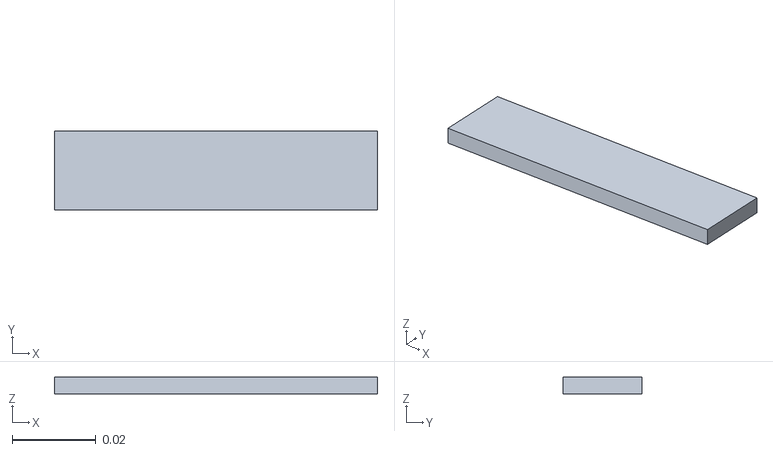
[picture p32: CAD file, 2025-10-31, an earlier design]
ENTREGABLES/ENTREGABLE 9/Part Studio 1 (6).stl
0.077 x 0.0188 x 0.004

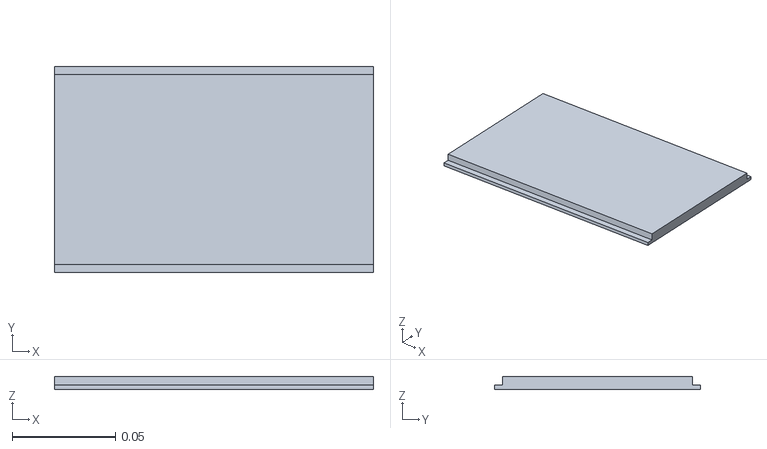
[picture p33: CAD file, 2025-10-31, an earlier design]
ENTREGABLES/ENTREGABLE 9/Part Studio 1 (2).stl
0.155 x 0.1 x 0.0062

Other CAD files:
ENTREGABLES/ENTREGABLE 9/Part Studio 1 (2) (1).x_t
ENTREGABLES/ENTREGABLE 9/Part Studio 1 (7).x_t

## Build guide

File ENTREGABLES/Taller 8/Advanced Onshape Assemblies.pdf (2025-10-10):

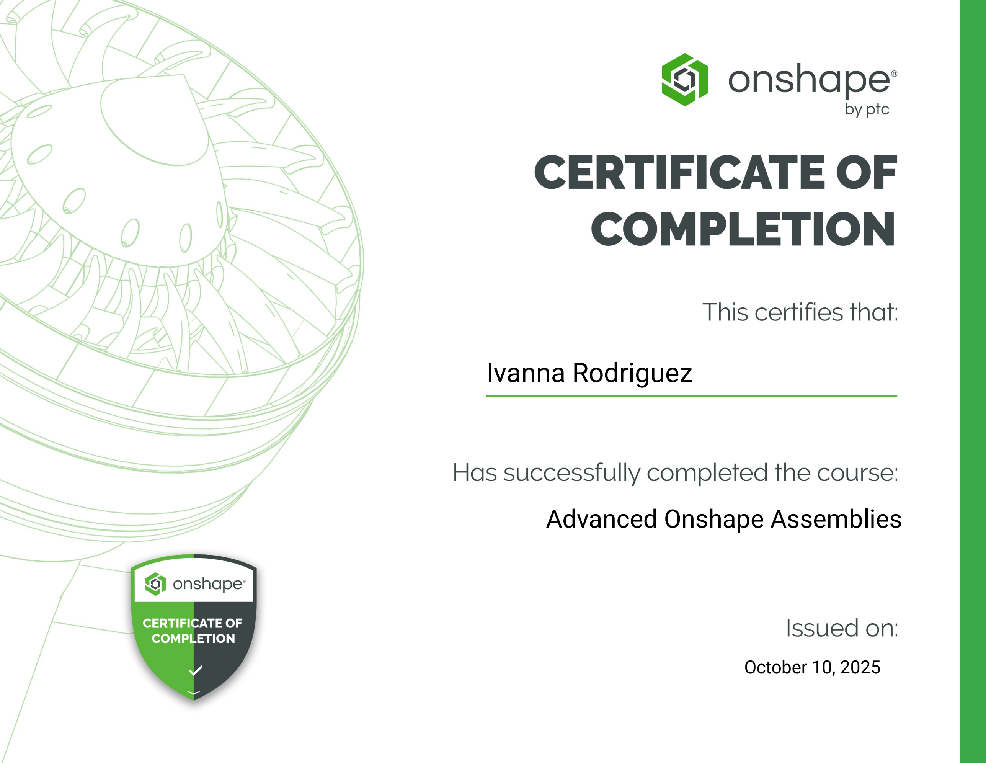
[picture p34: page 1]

Ivanna Rodriguez

Advanced Onshape Assemblies

October 10, 2025

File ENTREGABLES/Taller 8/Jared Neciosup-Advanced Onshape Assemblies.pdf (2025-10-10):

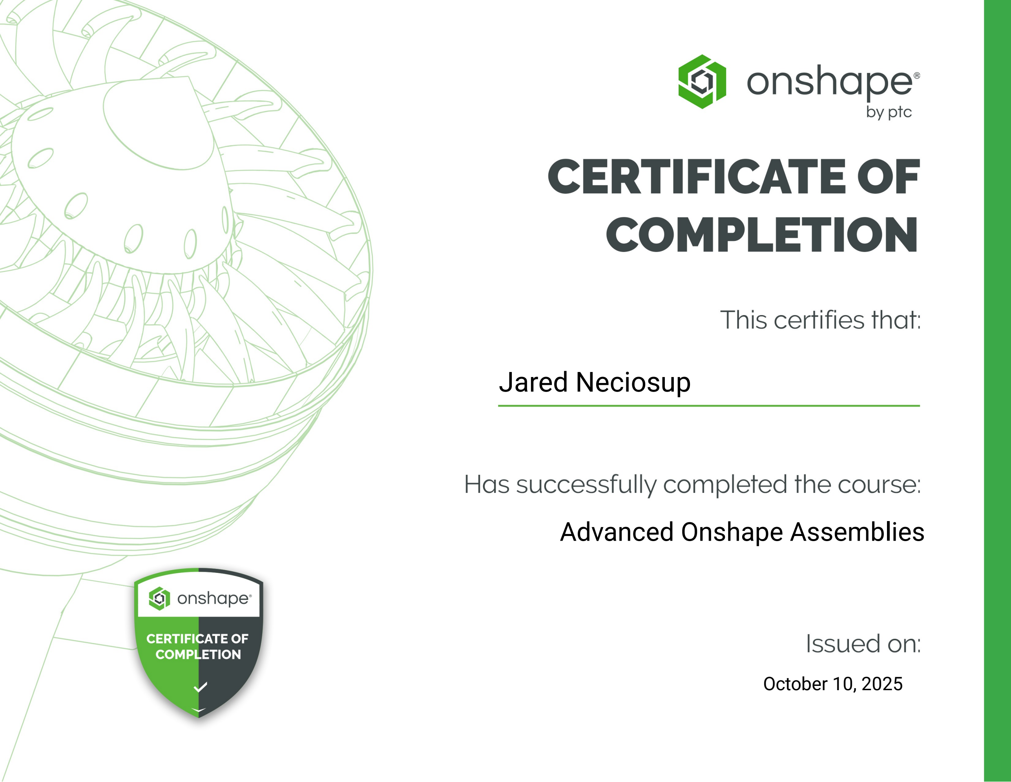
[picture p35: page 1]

Jared Neciosup

Advanced Onshape Assemblies

October 10, 2025

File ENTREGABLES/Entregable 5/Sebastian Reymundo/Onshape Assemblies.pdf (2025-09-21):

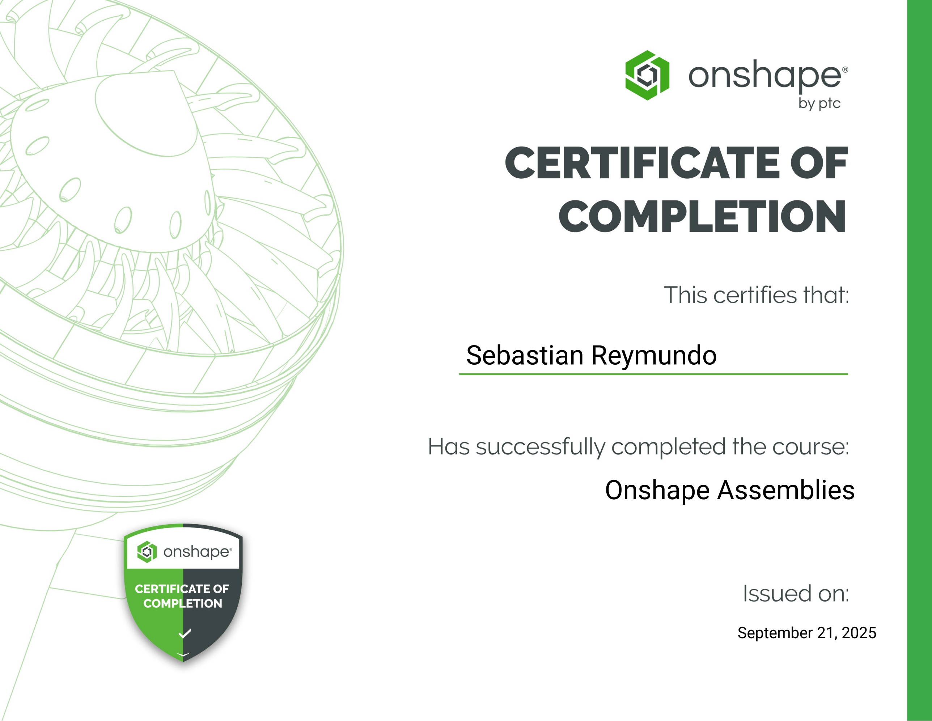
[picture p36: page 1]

Sebastian Reymundo

September 21, 2025

Onshape Assemblies

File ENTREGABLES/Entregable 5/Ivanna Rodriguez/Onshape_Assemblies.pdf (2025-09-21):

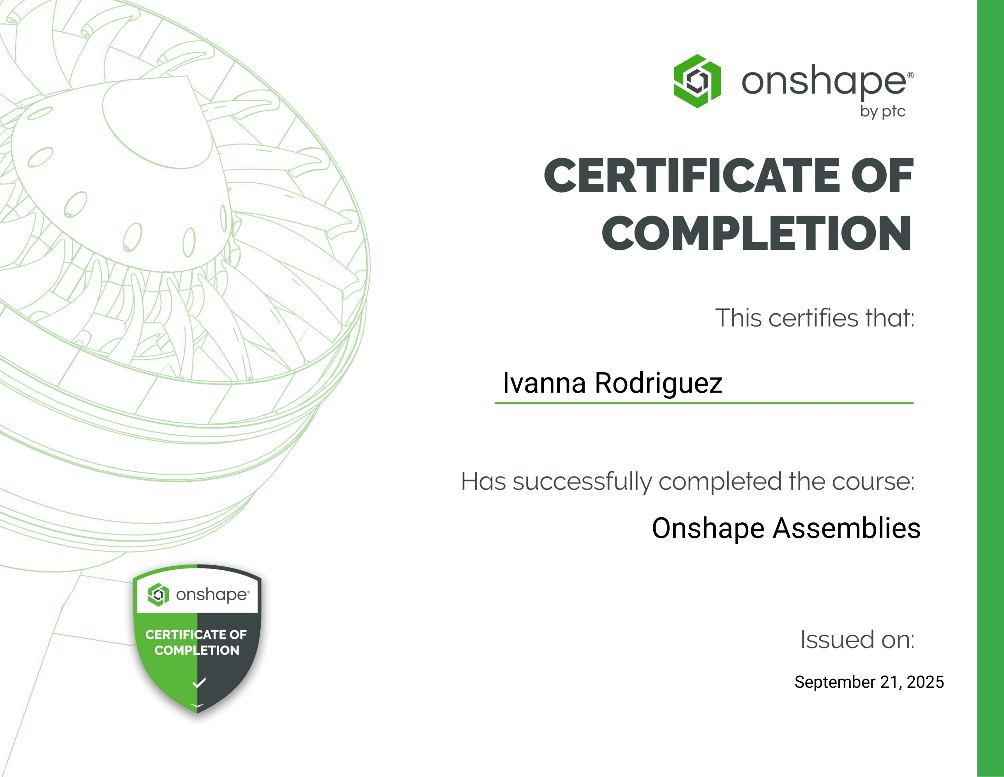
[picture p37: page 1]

Ivanna Rodriguez

September 21, 2025

Onshape Assemblies

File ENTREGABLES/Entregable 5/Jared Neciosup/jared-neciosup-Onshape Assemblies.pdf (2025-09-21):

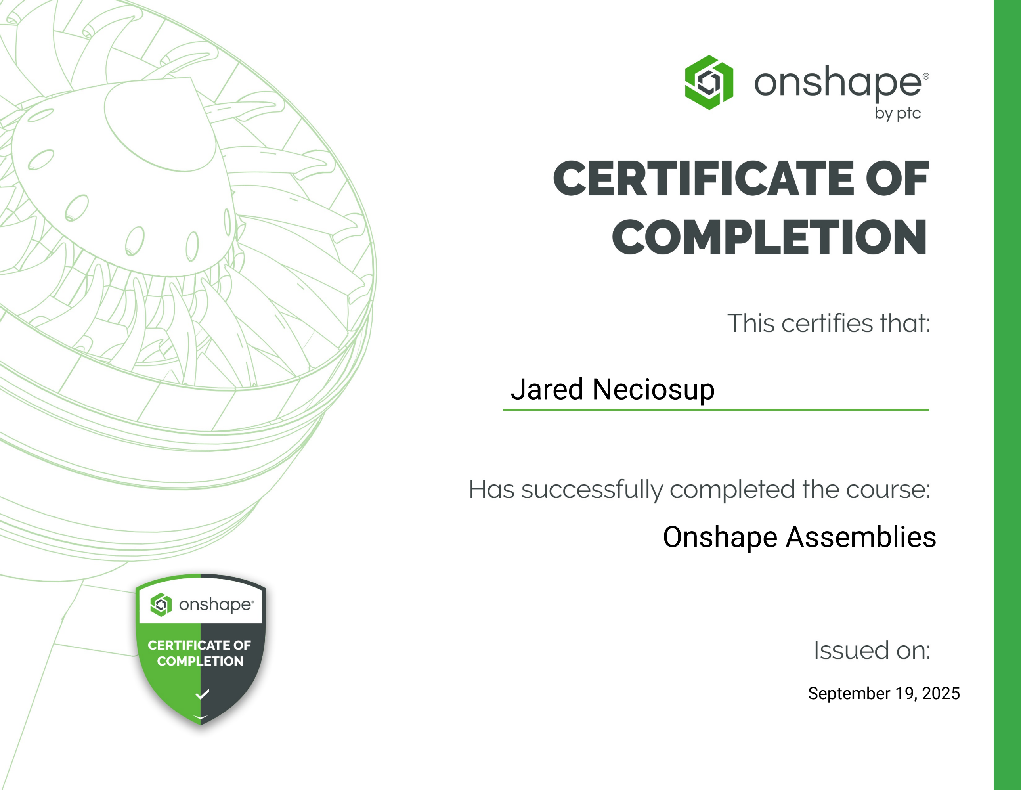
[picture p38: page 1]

Jared Neciosup

September 19, 2025

Onshape Assemblies
